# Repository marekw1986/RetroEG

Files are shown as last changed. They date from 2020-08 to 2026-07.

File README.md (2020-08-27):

# RetroEG

## Overwiev
This is repository of firmware for RetroGeiger project - a Geiger counter made of retro parts. 
It uses WDC65C02 CPU and some vintage peripherals, like R65C51 UART, M6242B RTC or MC6840 timer. 
You can find description of this project on my [Hackaday.io profile](https://hackaday.io/project/167980-retrogeiger).

This project is still in development.

## Required tools
You need [cc65](https://github.com/cc65/cc65) to build this project.

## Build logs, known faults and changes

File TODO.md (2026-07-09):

# RetroGeiger
Geiger counter build around 6502 CPU

### Tasks
- [ ] Debug write issue. For some reason writing to 8255 and EEPROM fails. Maybe /WR signal should be delayed.

### Completed Column ✓
- [x] Add modbus support

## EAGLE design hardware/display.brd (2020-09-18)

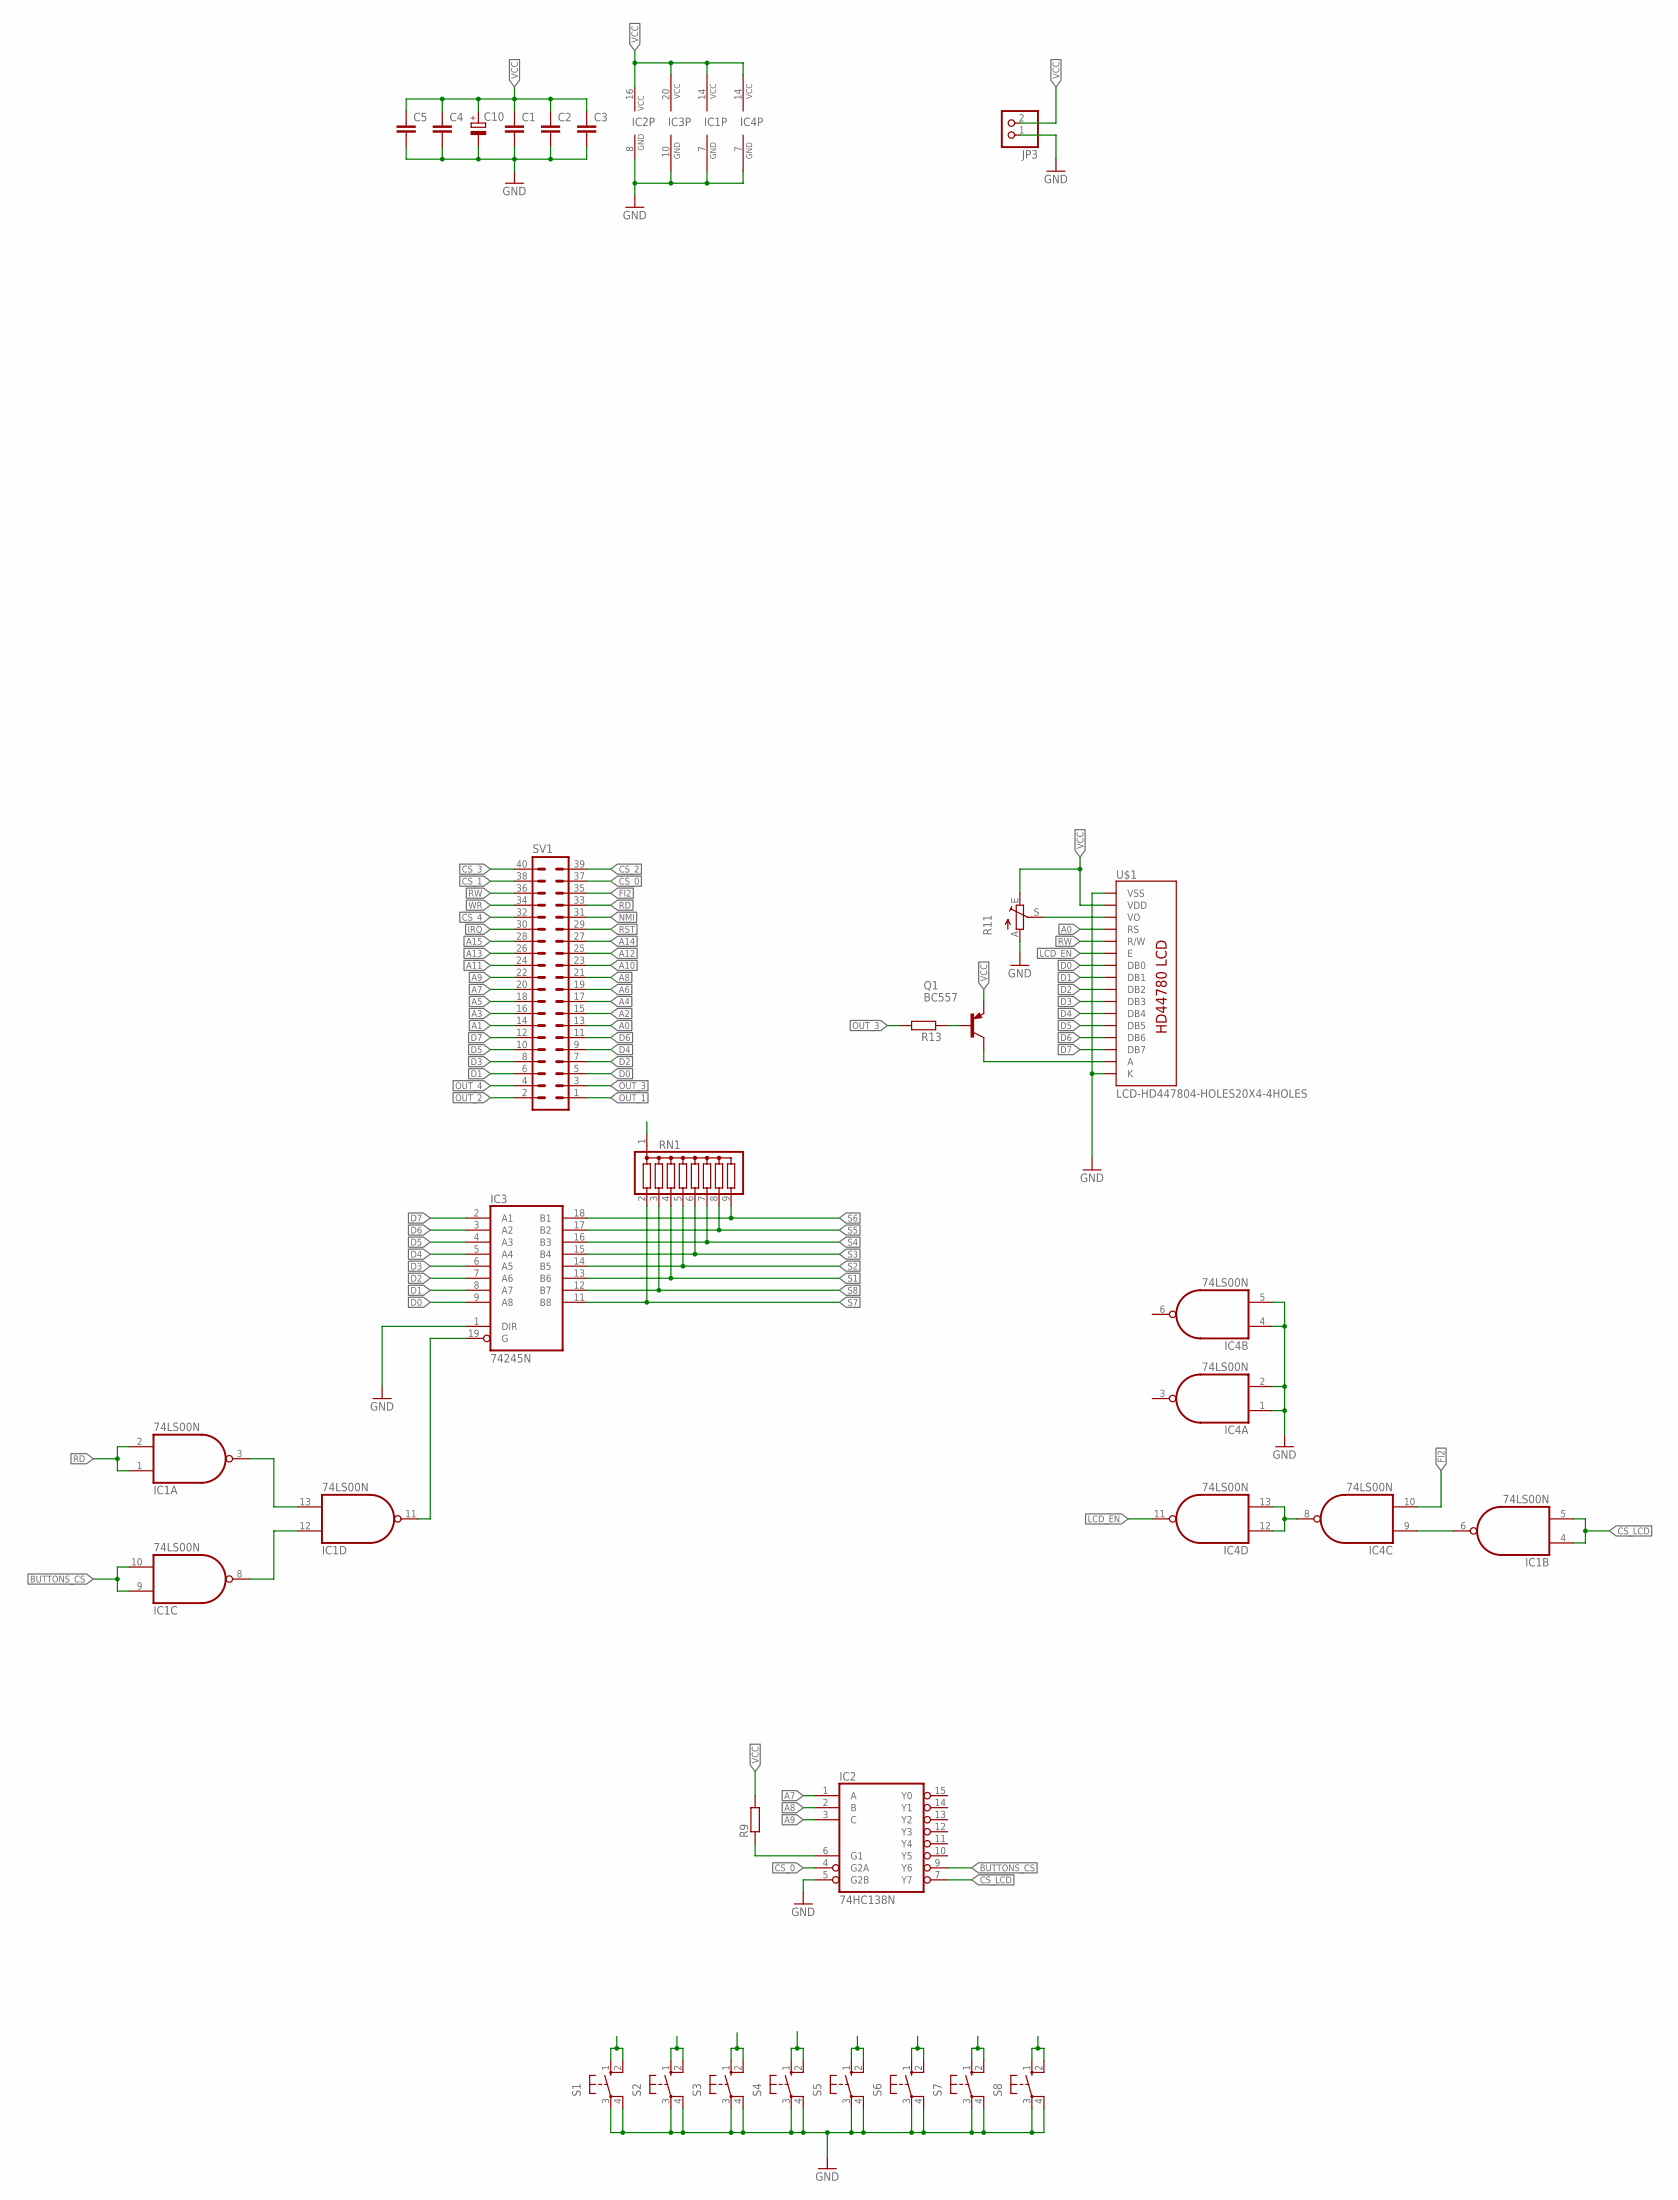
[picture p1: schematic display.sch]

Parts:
C1: C-EUC0603; C0603
C2, C3, C4, C5: C-EUC1206; C1206
C10: CPOL-EUE5-10.5; E5-10,5
IC1, IC4: 74LS00N; DIL14
IC2: 74HC138N; DIL16
IC3: 74245N; DIL20
JP3: PINHD-1X2/90; 1X02/90
Q1: BC557; TO92
R9, R13: R-EU_0204/7; 0204/7
R11: TRIM_EU-B25U; B25U
RN1: G08R; SIL9
S1, S2, S3, S4, S5, S6, S7, S8: 40-XX; B3F-40XX
SV1: ML40L
U$1: LCD-HD447804-HOLES20X4-4HOLES; LCD-20X4-4HOLES

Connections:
A0: SV1.13, U$1.P$4 (RS)
A1: SV1.14
A2: SV1.15
A3: SV1.16
A4: SV1.17
A5: SV1.18
A6: SV1.19
A7: IC2.1 (A), SV1.20
A8: IC2.2 (B), SV1.21
A9: IC2.3 (C), SV1.22
A10: SV1.23
A11: SV1.24
A12: SV1.25
A13: SV1.26
A14: SV1.27
A15: SV1.28
BUTTONS_CS: IC1.9 (I0), IC1.10 (I1), IC2.9 (Y6)
CS_0: IC2.4 (G2A), SV1.37
CS_1: SV1.38
CS_2: SV1.39
CS_3: SV1.40
CS_4: SV1.32
CS_LCD: IC1.4 (I0), IC1.5 (I1), IC2.7 (Y7)
D0: IC3.9 (A8), SV1.5, U$1.P$7 (DB0)
D1: IC3.8 (A7), SV1.6, U$1.P$8 (DB1)
D2: IC3.7 (A6), SV1.7, U$1.P$9 (DB2)
D3: IC3.6 (A5), SV1.8, U$1.P$10 (DB3)
D4: IC3.5 (A4), SV1.9, U$1.P$11 (DB4)
D5: IC3.4 (A3), SV1.10, U$1.P$12 (DB5)
D6: IC3.3 (A2), SV1.11, U$1.P$13 (DB6)
D7: IC3.2 (A1), SV1.12, U$1.P$14 (DB7)
FI2: IC4.10 (I1), SV1.35
GND: C1.2, C2.2, C3.2, C4.2, C5.2, C10.-, IC1.7 (GND), IC2.5 (G2B), IC2.8 (GND), IC3.1 (DIR), IC3.10 (GND), IC4.1 (I0), IC4.2 (I1), IC4.4 (I0), IC4.5 (I1), IC4.7 (GND), JP3.1, R11.A, S1.3, S1.4 (P1), S2.3, S2.4 (P1), S3.3, S3.4 (P1), S4.3, S4.4 (P1), S5.3, S5.4 (P1), S6.3, S6.4 (P1), S7.3, S7.4 (P1), S8.3, S8.4 (P1), U$1.P$1 (VSS), U$1.P$16 (K)
IRQ: SV1.30
LCD_EN: IC4.11 (O), U$1.P$6 (E)
unnamed: IC1.11 (O), IC3.19 (G)
unnamed: Q1.3 (C), U$1.P$15 (A)
unnamed: IC4.8 (O), IC4.12 (I0), IC4.13 (I1)
unnamed: IC1.6 (O), IC4.9 (I0)
unnamed: Q1.2 (B), R13.1
unnamed: IC1.3 (O), IC1.13 (I1)
unnamed: IC1.8 (O), IC1.12 (I0)
unnamed: IC2.6 (G1), R9.1
unnamed: R11.S, U$1.P$3 (VO)
NMI: SV1.31
OUT_1: SV1.1
OUT_2: SV1.2
OUT_3: R13.2, SV1.3
OUT_4: SV1.4
RD: IC1.1 (I0), IC1.2 (I1), SV1.33
RST: SV1.29
RW: SV1.36, U$1.P$5 (R/W)
S1: IC3.13 (B6), RN1.4, S1.1 (S), S1.2 (S1)
S2: IC3.14 (B5), RN1.5, S2.1 (S), S2.2 (S1)
S3: IC3.15 (B4), RN1.6, S3.1 (S), S3.2 (S1)
S4: IC3.16 (B3), RN1.7, S4.1 (S), S4.2 (S1)
S5: IC3.17 (B2), RN1.8, S5.1 (S), S5.2 (S1)
S6: IC3.18 (B1), RN1.9, S6.1 (S), S6.2 (S1)
S7: IC3.11 (B8), RN1.2, S7.1 (S), S7.2 (S1)
S8: IC3.12 (B7), RN1.3, S8.1 (S), S8.2 (S1)
VCC: C1.1, C2.1, C3.1, C4.1, C5.1, C10.+, IC1.14 (VCC), IC2.16 (VCC), IC3.20 (VCC), IC4.14 (VCC), JP3.2, Q1.1 (E), R9.2, R11.E, RN1.1, U$1.P$2 (VDD)
WR: SV1.34

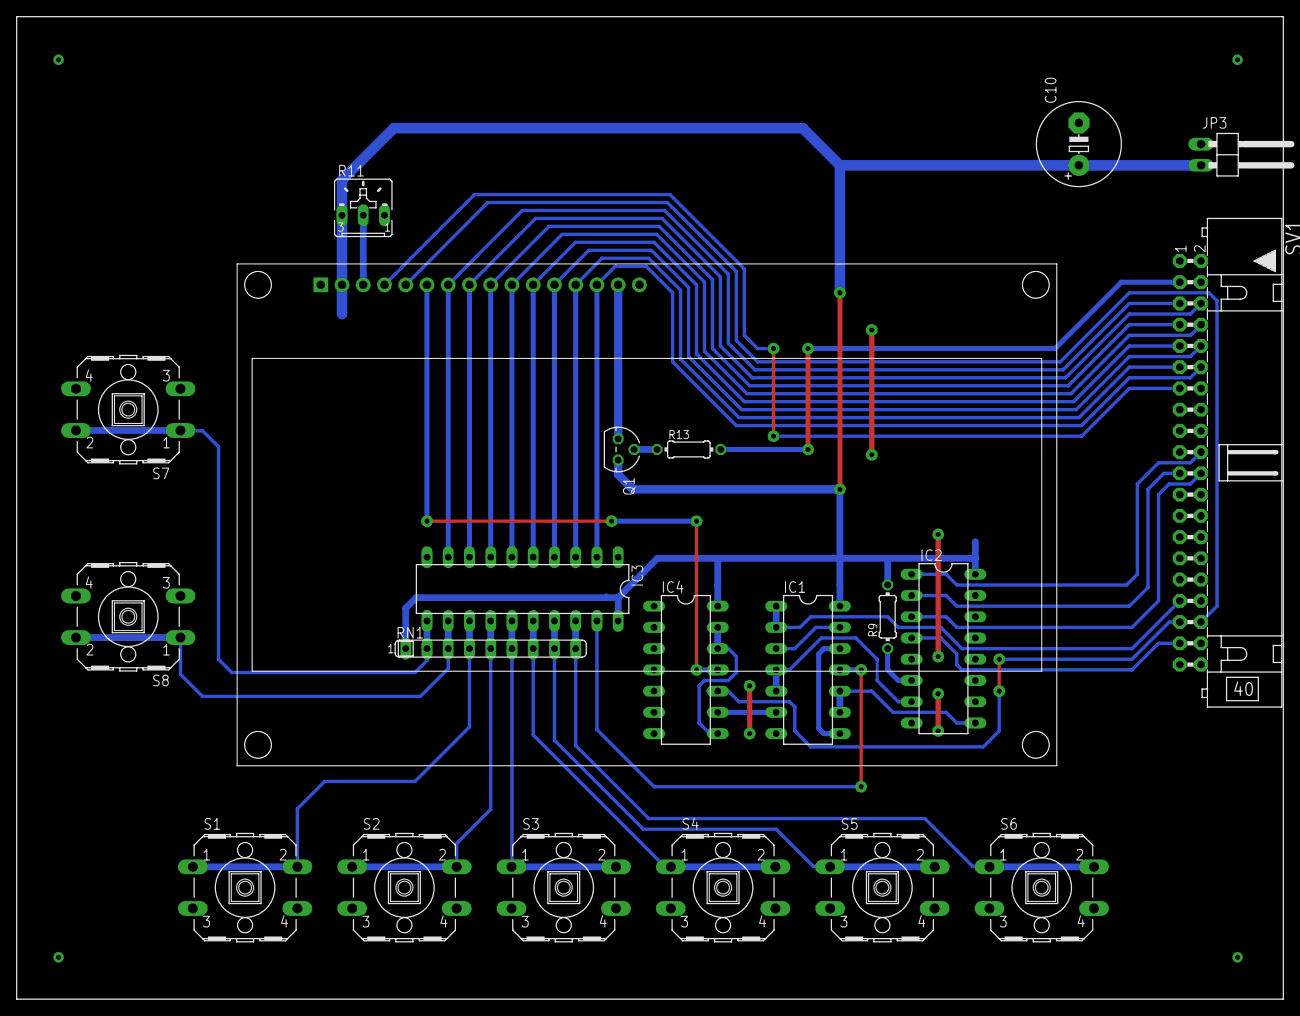
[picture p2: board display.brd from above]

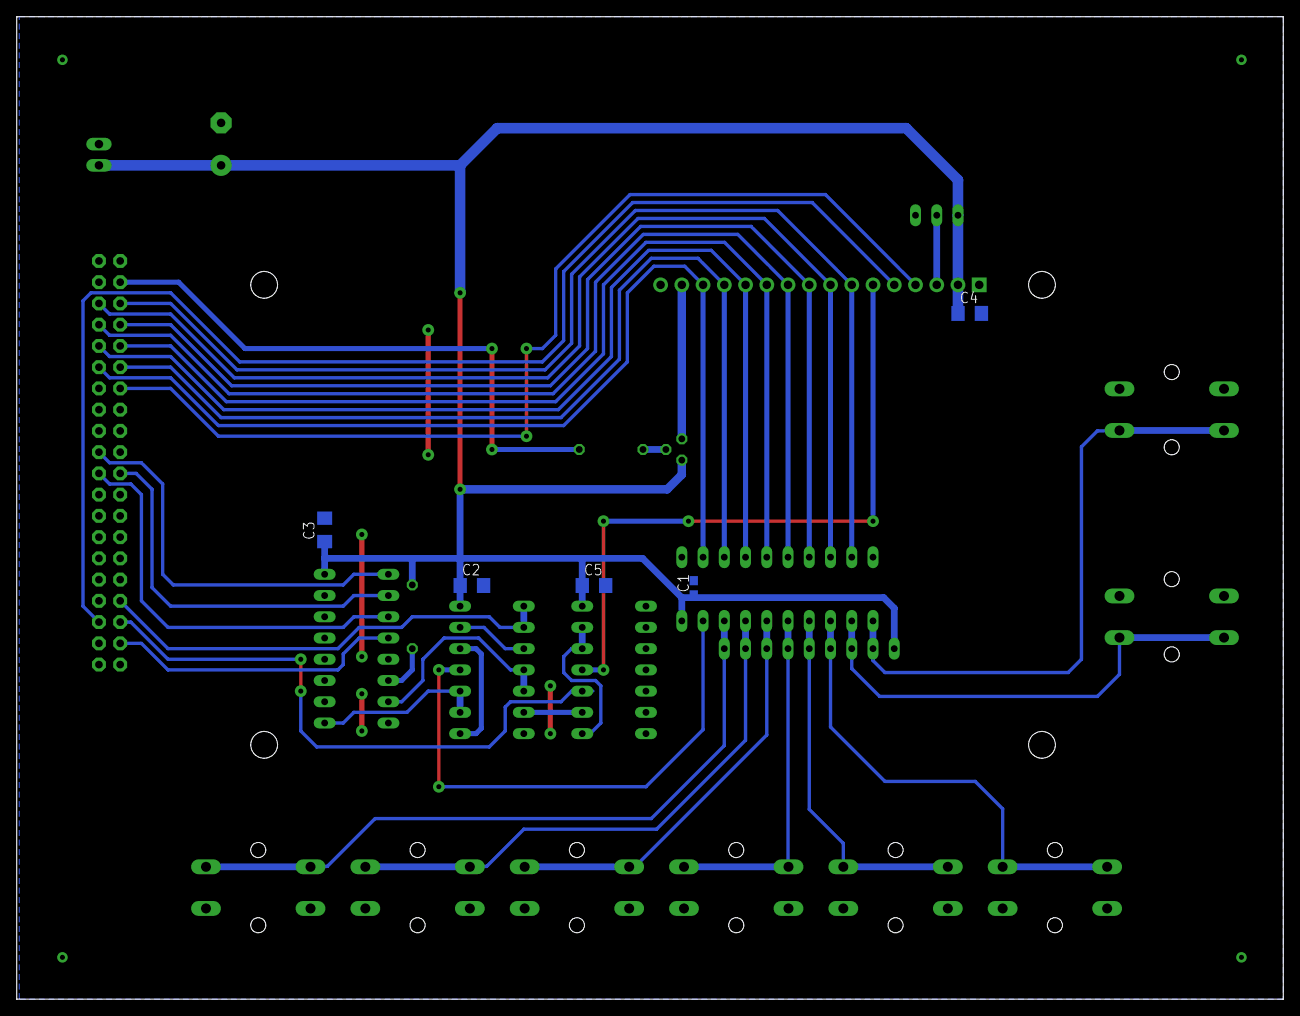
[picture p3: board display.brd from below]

Board: 2 copper layers, 151.4 x 117.5 mm, 26 parts (5 on the bottom side), 39 nets.

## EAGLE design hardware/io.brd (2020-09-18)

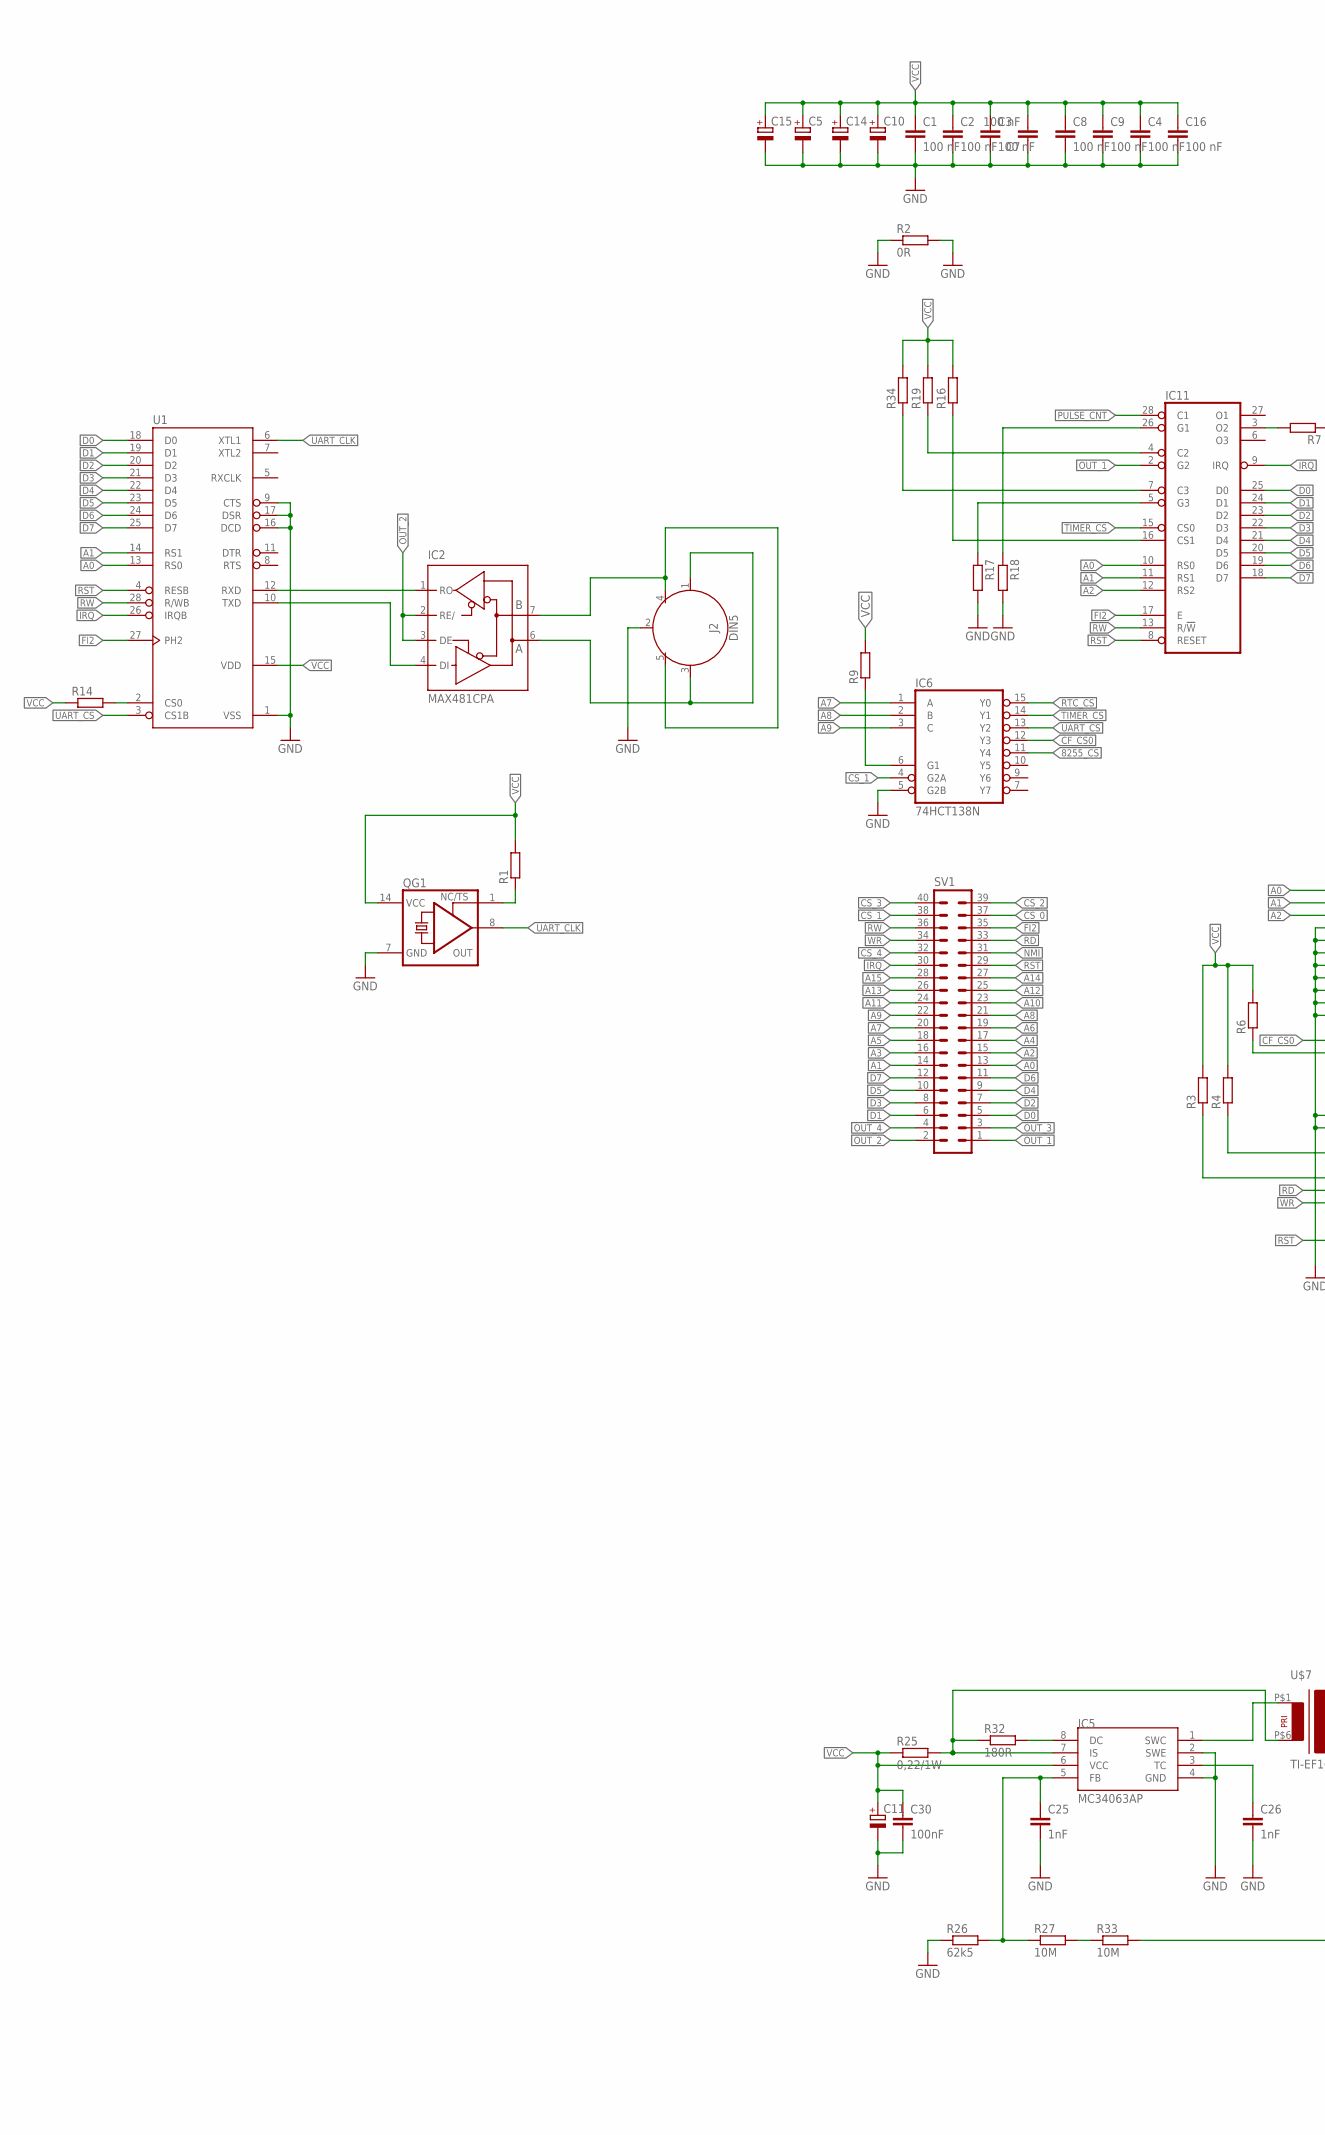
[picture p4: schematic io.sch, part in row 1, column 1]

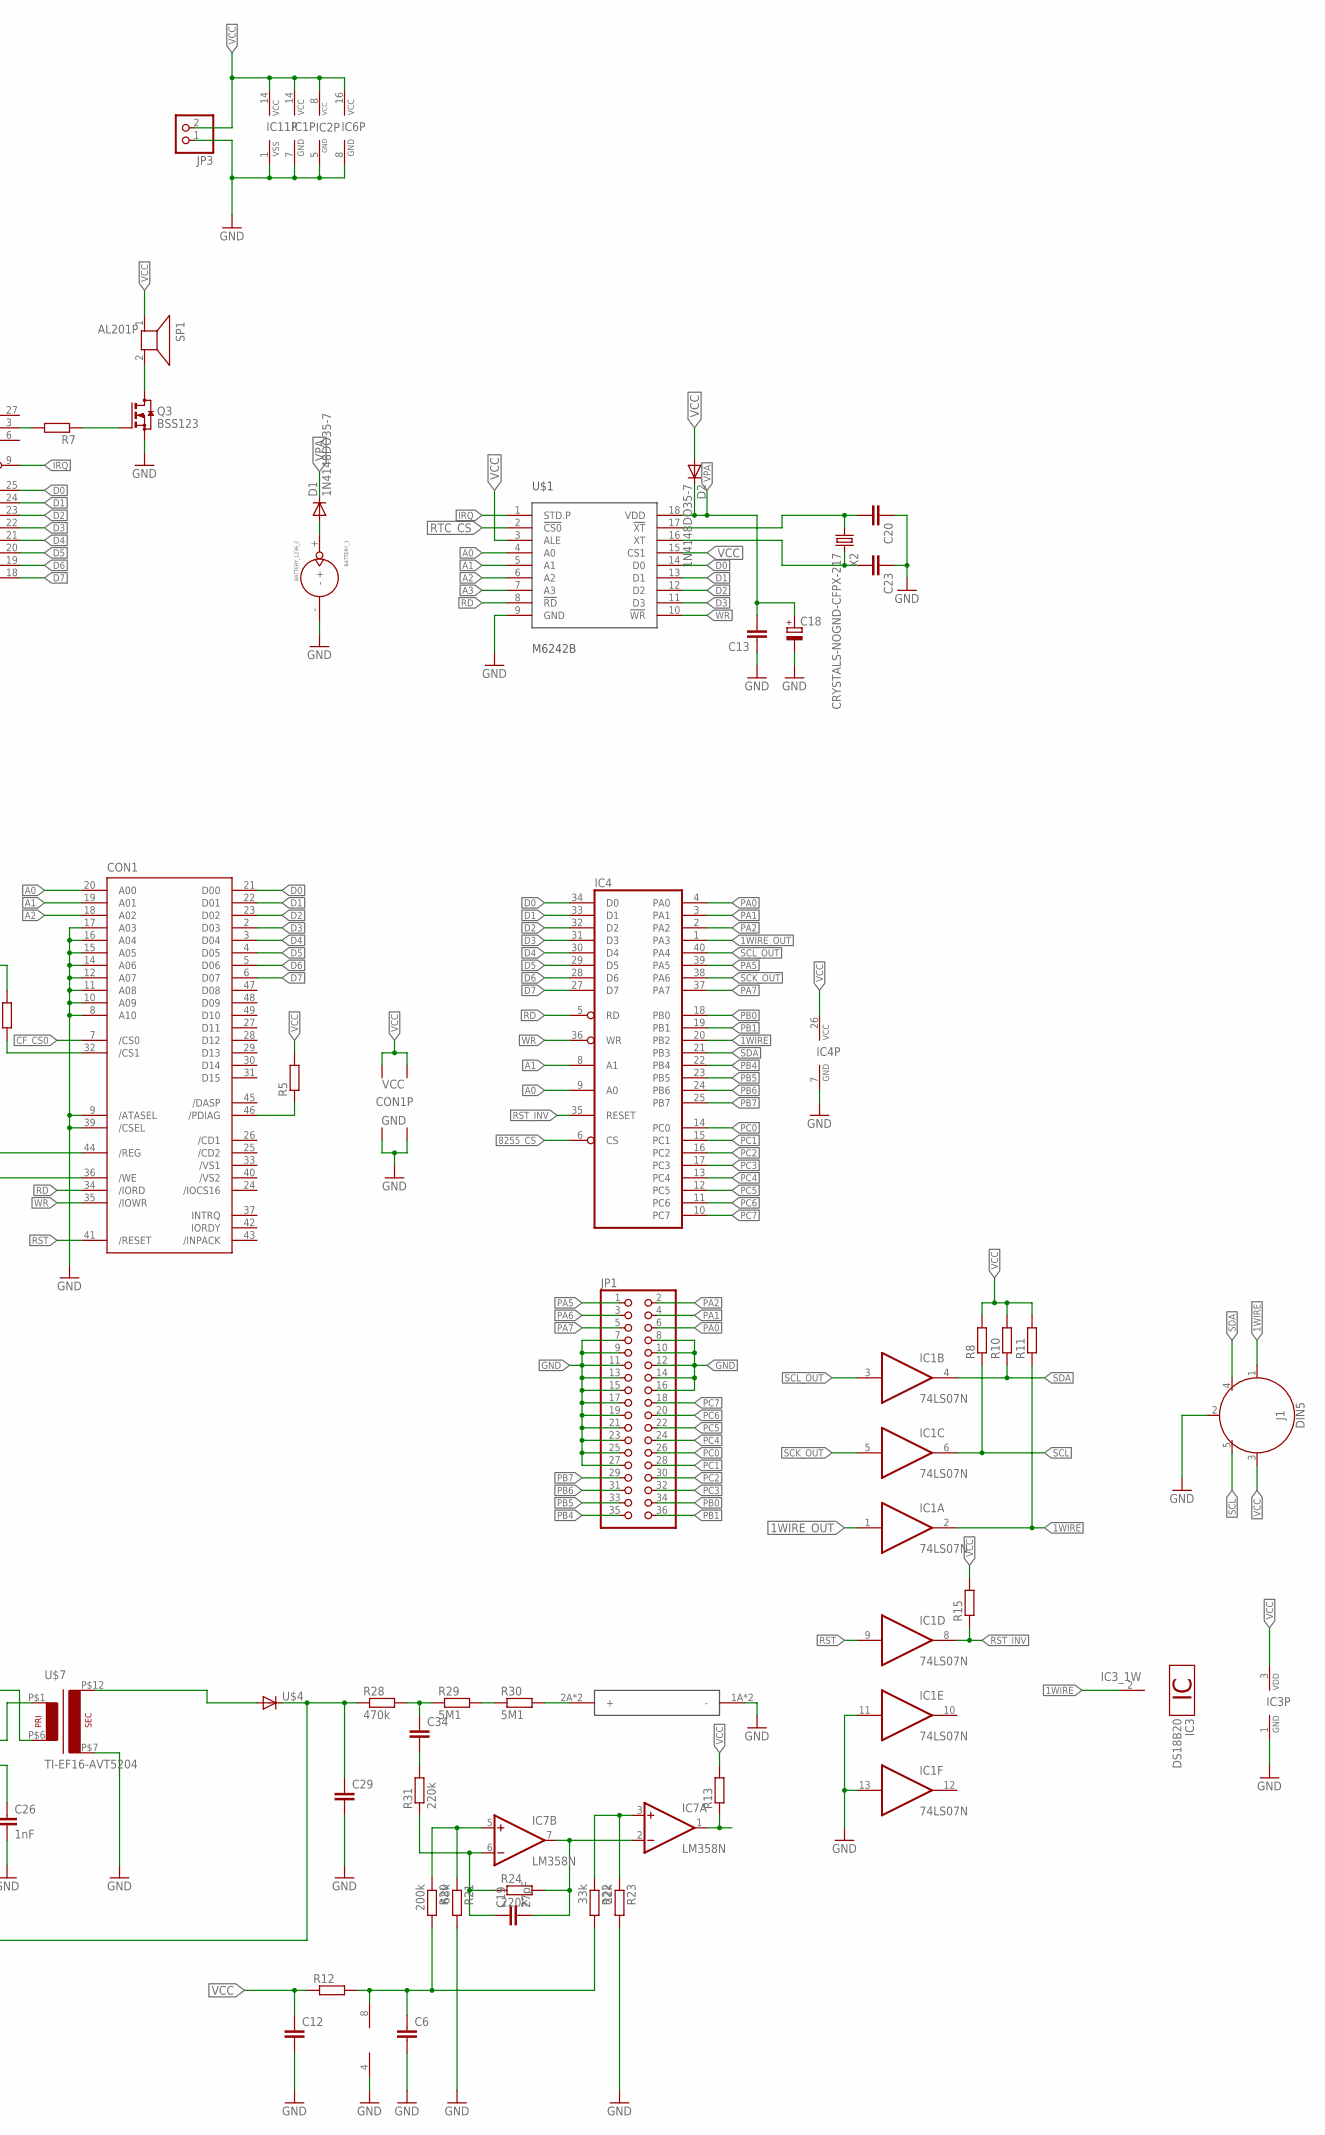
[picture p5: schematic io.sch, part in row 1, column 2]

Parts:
BATTERY_1: BATTERY_1236_C
C1, C2, C3, C8, C9: 100 nF; C1206
C4, C7, C16: 100 nF; C0603
C5: CPOL-EUSMCC; SMC_C
C6, C12, C13, C20, C23: C-EUC0603; C0603
C10, C15: CPOL-EUE5-10.5; E5-10,5
C11: CPOL-EUSMCE; SMC_E
C14: CPOL-EUE3.5-8; E3,5-8
C18: CPOL-EUSMCB; SMC_B
C19: 27pF; C0603
C25, C26: 1nF; C0603
C29: C-EU225-113X268; C225-113X268
C30: 100nF; C0603
C34: C-EU050-024X044; C050-024X044
CON1: CF-CARD-IDE_MODE; MI20-50PD-SF
D1, D2: 1N4148DO35-7; DO35-7
IC1: 74LS07N; DIL14
IC2: MAX481CPA; DIL08
IC3: DS18B20; TO92-
IC4: 8255A; DIL40
IC5: MC34063AP; DIL08
IC6: 74HCT138N; DIL16
IC7: LM358N; DIL08
IC11: 6840; DIL28
J1, J2: DIN5; DIN5-RA-PTH
JP1: PINHD-2X18; 2X18
JP3: PINHD-1X2/90; 1X02/90
Q3: BSS123; SOT23
QG1: XO-14; DIL14S
R1, R9: R-EU_R1206; R1206
R2: 0R; M1206
R3, R4, R5, R6, R13, R14, R15, R18, R34: R-EU_R0603; R0603
R7, R19: R-EU_0204/5; 0204/5
R8, R10, R11, R12, R17: R-EU_0204/7; 0204/7
R16: R-EU_R0402; R0402
R20: 200k; R0603
R21: 68k; R0603
R22: 33k; R0603
R23: 22k; R0603
R24: 220k; R0603
R25: 0,22/1W; R2010
R26: 62k5; R1206
R27, R33: 10M; 0204/7
R28: 470k; R2512
R29, R30: 5M1; R2512
R31: 220k; 0204/7
R32: 180R; R0805
SP1: AL201P
SV1: ML40L
U1: G65SC51P; DIP-28
U$1: M6242B; DIL18
U$4: DIODE-MELF-MLL41; MELF-MLL41
U$5: STS5; GEIGERTUBE
U$7: TI-EF16-AVT5204; EF16-K-H-12P-12,5
X2: CRYSTALS-NOGND-CFPX-217; 3.2X1.5-2-PAD

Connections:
1WIRE: IC1.2 (O), IC3.2 (1W), IC4.20 (PB2), J1.1, R11.1
1WIRE_OUT: IC1.1 (I), IC4.1 (PA3)
8255_CS: IC4.6 (CS), IC6.11 (Y4)
A0: CON1.20 (A00), IC4.9 (A0), IC11.10 (RS0), SV1.13, U1.13 (RS0), U$1.4 (A0)
A1: CON1.19 (A01), IC4.8 (A1), IC11.11 (RS1), SV1.14, U1.14 (RS1), U$1.5 (A1)
A2: CON1.18 (A02), IC11.12 (RS2), SV1.15, U$1.6 (A2)
A3: SV1.16, U$1.7 (A3)
A4: SV1.17
A5: SV1.18
A6: SV1.19
A7: IC6.1 (A), SV1.20
A8: IC6.2 (B), SV1.21
A9: IC6.3 (C), SV1.22
A10: SV1.23
A11: SV1.24
A12: SV1.25
A13: SV1.26
A14: SV1.27
A15: SV1.28
A_3V: C6.1, IC7.8 (V+), R12.2, R20.2, R22.2
CF_CS0: CON1.7 (/CS0), IC6.12 (Y3)
CS_0: SV1.37
CS_1: IC6.4 (G2A), SV1.38
CS_2: SV1.39
CS_3: SV1.40
CS_4: SV1.32
D0: CON1.21 (D00), IC4.34 (D0), IC11.25 (D0), SV1.5, U1.18 (D0), U$1.14 (D0)
D1: CON1.22 (D01), IC4.33 (D1), IC11.24 (D1), SV1.6, U1.19 (D1), U$1.13 (D1)
D2: CON1.23 (D02), IC4.32 (D2), IC11.23 (D2), SV1.7, U1.20 (D2), U$1.12 (D2)
D3: CON1.2 (D03), IC4.31 (D3), IC11.22 (D3), SV1.8, U1.21 (D3), U$1.11 (D3)
D4: CON1.3 (D04), IC4.30 (D4), IC11.21 (D4), SV1.9, U1.22 (D4)
D5: CON1.4 (D05), IC4.29 (D5), IC11.20 (D5), SV1.10, U1.23 (D5)
D6: CON1.5 (D06), IC4.28 (D6), IC11.19 (D6), SV1.11, U1.24 (D6)
D7: CON1.6 (D07), IC4.27 (D7), IC11.18 (D7), SV1.12, U1.25 (D7)
FI2: IC11.17 (E), SV1.35, U1.27 (PH2)
GND: BATTERY_1.-, C1.2, C2.2, C3.2, C4.2, C5.-, C6.2, C7.1, C8.2, C9.2, C10.-, C11.-, C12.2, C13.1, C14.-, C15.-, C16.2, C18.-, C20.1, C23.1, C25.2, C26.2, C29.2, C30.2, CON1.1 (GND1), CON1.8 (A10), CON1.9 (/ATASEL), CON1.10 (A09), CON1.11 (A08), CON1.12 (A07), CON1.14 (A06), CON1.15 (A05), CON1.16 (A04), CON1.17 (A03), CON1.39 (/CSEL), CON1.50 (GND2), IC1.7 (GND), IC1.11 (I), IC1.13 (I), IC2.5 (GND), IC3.1 (GND), IC4.7 (GND), IC5.2 (SWE), IC5.4 (GND), IC6.5 (G2B), IC6.8 (GND), IC7.4 (V-), IC11.1 (VSS), J1.2, J2.2, JP1.7, JP1.8, JP1.9, JP1.10, JP1.11, JP1.12, JP1.13, JP1.14, JP1.15, JP1.16, JP1.17, JP1.19, JP1.21, JP1.23, JP1.25, JP1.27, JP3.1, Q3.2 (S), QG1.7 (GND), R2.1, R2.2, R17.2, R18.2, R21.2, R23.2, R26.1, U1.1 (VSS), U1.9 (CTS), U1.16 (DCD), U1.17 (DSR), U$1.9 (GND), U$5.1A (-), U$5.1B (-), U$7.P$7 (P7)
HV: C29.1, R28.1, R33.2, U$4.C
IRQ: IC11.9 (IRQ), SV1.30, U1.26 (IRQB), U$1.1 (STD.P)
unnamed: QG1.1 (TS), R1.1
unnamed: C19.1, IC7.6 (-IN), R24.1, R31.1
unnamed: IC5.7 (IS), R25.2, R32.1, U$7.P$6 (P6)
unnamed: U$4.A, U$7.P$12 (P12)
unnamed: C26.1, IC5.3 (TC)
unnamed: C25.1, IC5.5 (FB), R26.2, R27.1
unnamed: R30.2, U$5.2A (+), U$5.2B (+)
unnamed: IC11.3 (O2), R7.2
unnamed: CON1.32 (/CS1), R6.1
unnamed: Q3.3 (D), SP1.2
unnamed: C19.2, IC7.2 (-IN), IC7.7 (OUT), R24.2
unnamed: IC6.6 (G1), R9.1
unnamed: CON1.44 (/REG), R4.1
unnamed: CON1.36 (/WE), R3.1
unnamed: CON1.46 (/PDIAG), R5.1
unnamed: BATTERY_1.+, D1.A
unnamed: R29.2, R30.1
unnamed: C34.1, R28.2, R29.1
unnamed: C34.2, R31.2
unnamed: IC7.5 (+IN), R20.1, R21.1
unnamed: IC7.3 (+IN), R22.1, R23.1
unnamed: R14.2, U1.2 (CS0)
unnamed: IC11.16 (CS1), R16.1
unnamed: IC5.1 (SWC), U$7.P$1 (P1)
unnamed: IC5.8 (DC), R32.2
unnamed: R27.2, R33.1
unnamed: IC11.5 (G3), R17.1
unnamed: IC11.26 (G1), R18.1
unnamed: IC11.4 (C2), R19.1
unnamed: IC11.7 (C3), R34.1
NMI: SV1.31
OUT_1: IC11.2 (G2), SV1.1
OUT_2: IC2.2 (RE/), IC2.3 (DE), SV1.2
OUT_3: SV1.3
OUT_4: SV1.4
PA0: IC4.4 (PA0), JP1.6
PA1: IC4.3 (PA1), JP1.4
PA2: IC4.2 (PA2), JP1.2
PA5: IC4.39 (PA5), JP1.1
PA6: JP1.3
PA7: IC4.37 (PA7), JP1.5
PB0: IC4.18 (PB0), JP1.34
PB1: IC4.19 (PB1), JP1.36
PB4: IC4.22 (PB4), JP1.35
PB5: IC4.23 (PB5), JP1.33
PB6: IC4.24 (PB6), JP1.31
PB7: IC4.25 (PB7), JP1.29
PC0: IC4.14 (PC0), JP1.26
PC1: IC4.15 (PC1), JP1.28
PC2: IC4.16 (PC2), JP1.30
PC3: IC4.17 (PC3), JP1.32
PC4: IC4.13 (PC4), JP1.24
PC5: IC4.12 (PC5), JP1.22
PC6: IC4.11 (PC6), JP1.20
PC7: IC4.10 (PC7), JP1.18
PULSE_CNT: IC7.1 (OUT), IC11.28 (C1), R13.1
RD: CON1.34 (/IORD), IC4.5 (RD), SV1.33, U$1.8 (!RD)
RST: CON1.41 (/RESET), IC1.9 (I), IC11.8 (RESET), SV1.29, U1.4 (RESB)
RST_INV: IC1.8 (O), IC4.35 (RESET), R15.1
RTC_CS: IC6.15 (Y0), U$1.2 (!CS0)
RW: IC11.13 (R/!W), SV1.36, U1.28 (R/WB)
RXD: IC2.1 (RO), U1.12 (RXD)
RX_A: IC2.6 (A), J2.1, J2.3
RX_B: IC2.7 (B), J2.4, J2.5
SCK_OUT: IC1.5 (I), IC4.38 (PA6)
SCL: IC1.6 (O), J1.5, R8.1
SCL_OUT: IC1.3 (I), IC4.40 (PA4)
SDA: IC1.4 (O), IC4.21 (PB3), J1.4, R10.1
SOSCI: C20.2, U$1.17 (!XT), X2.1
SOSCO: C23.2, U$1.16 (XT), X2.2
TICK: Q3.1 (G), R7.1
TIMER_CS: IC6.14 (Y1), IC11.15 (CS0)
TXD: IC2.4 (DI), U1.10 (TXD)
UART_CLK: QG1.8 (OUT), U1.6 (XTL1)
UART_CS: IC6.13 (Y2), U1.3 (CS1B)
VCC: C1.1, C2.1, C3.1, C4.1, C5.+, C7.2, C8.1, C9.1, C10.+, C11.+, C12.1, C14.+, C15.+, C16.1, C30.1, CON1.13 (VCC2), CON1.38 (VCC1), D2.A, IC1.14 (VCC), IC2.8 (VCC), IC3.3 (VDD), IC4.26 (VCC), IC5.6 (VCC), IC6.16 (VCC), IC11.14 (VCC), J1.3, JP3.2, QG1.14 (VCC), R1.2, R3.2, R4.2, R5.2, R6.2, R8.2, R9.2, R10.2, R11.2, R12.1, R13.2, R14.1, R15.2, R16.2, R19.2, R25.1, R34.2, SP1.1, U1.15 (VDD), U$1.3 (ALE), U$1.15 (CS1)
VPA: C13.2, C18.+, D1.C, D2.C, U$1.18 (VDD)
WR: CON1.35 (/IOWR), IC4.36 (WR), SV1.34, U$1.10 (!WR)

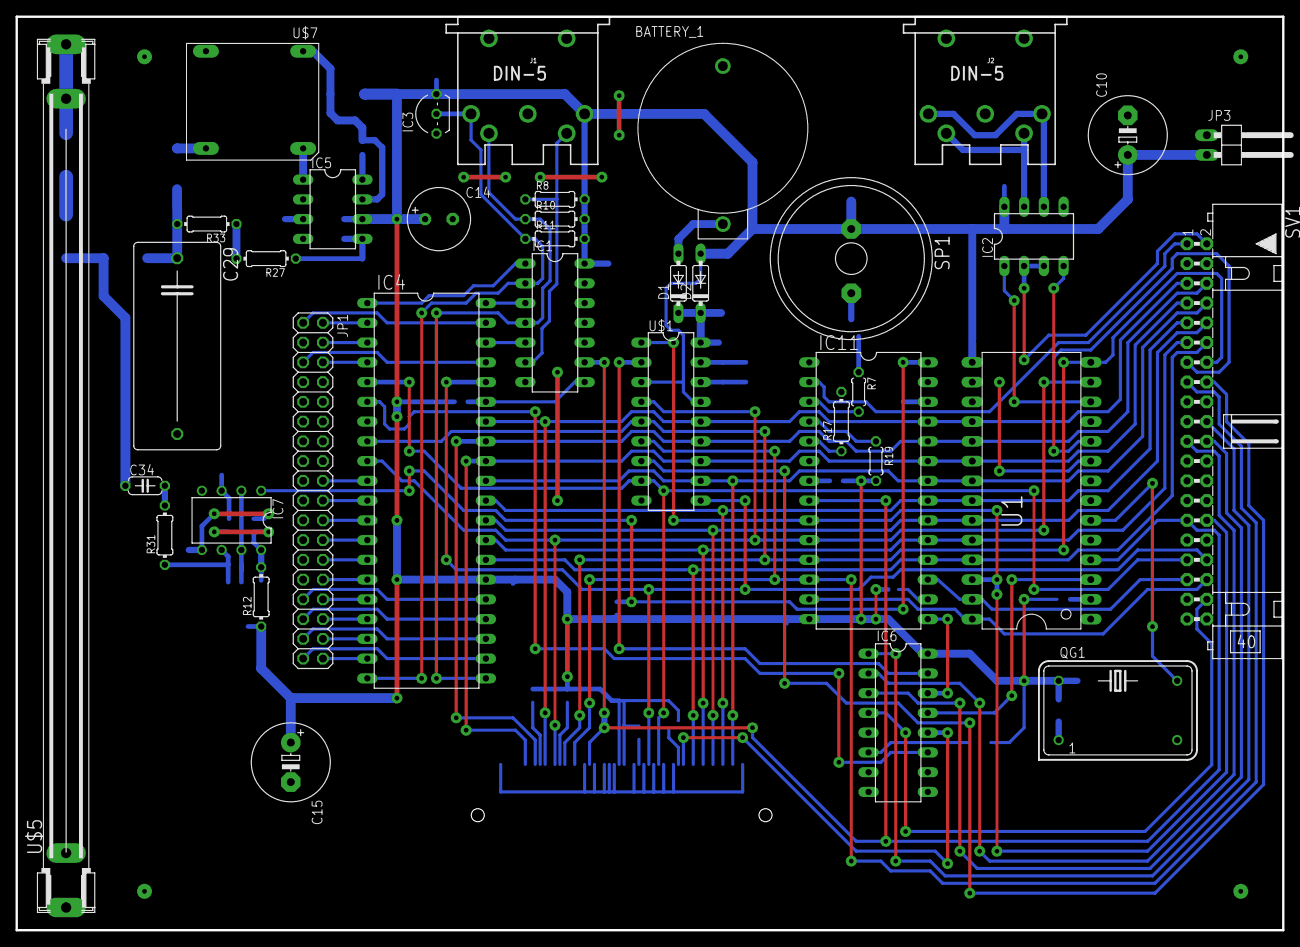
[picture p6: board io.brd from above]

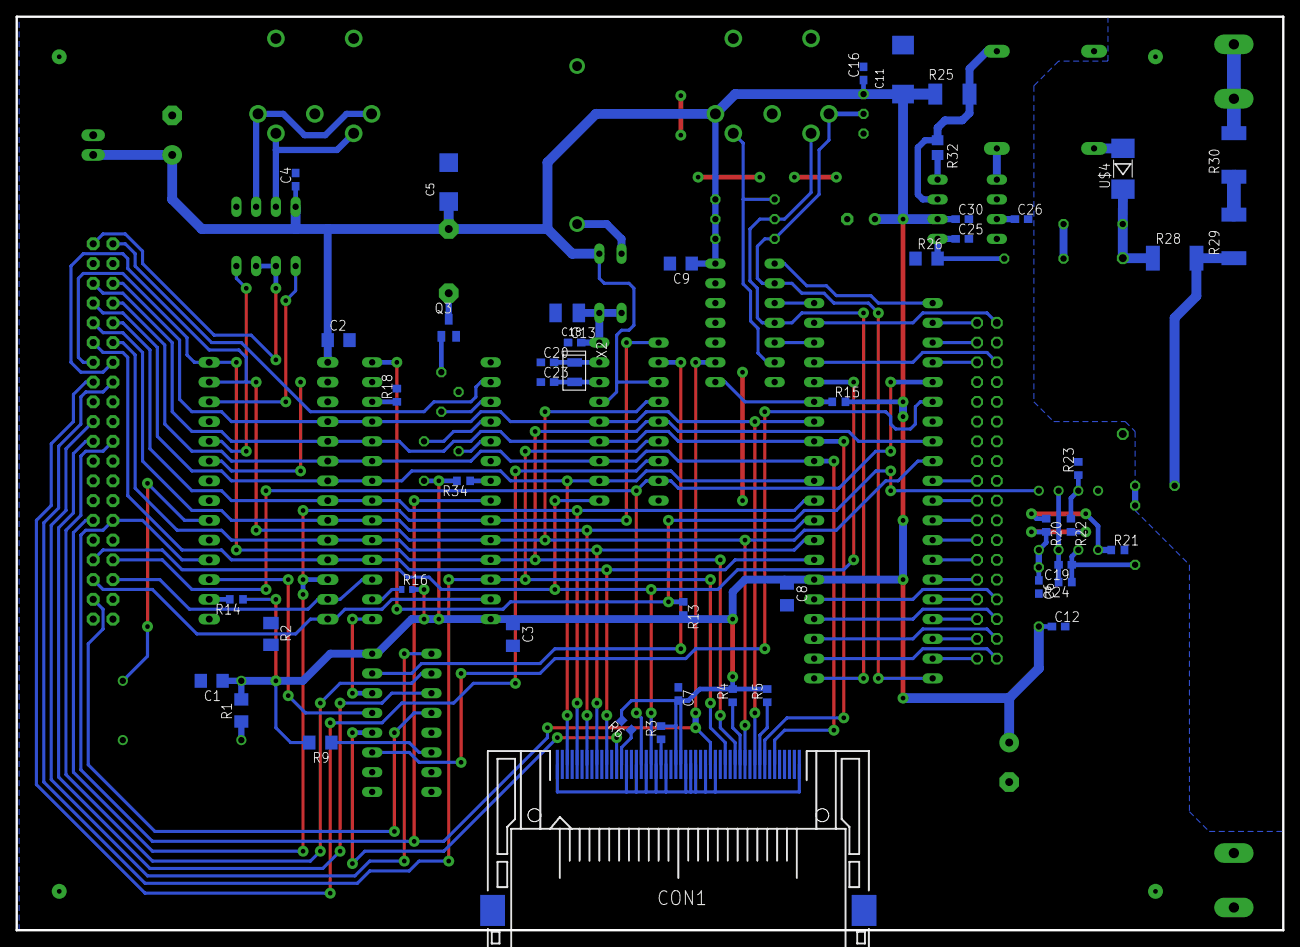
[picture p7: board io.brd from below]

Board: 2 copper layers, 162.9 x 117.5 mm, 85 parts (48 on the bottom side), 99 nets.

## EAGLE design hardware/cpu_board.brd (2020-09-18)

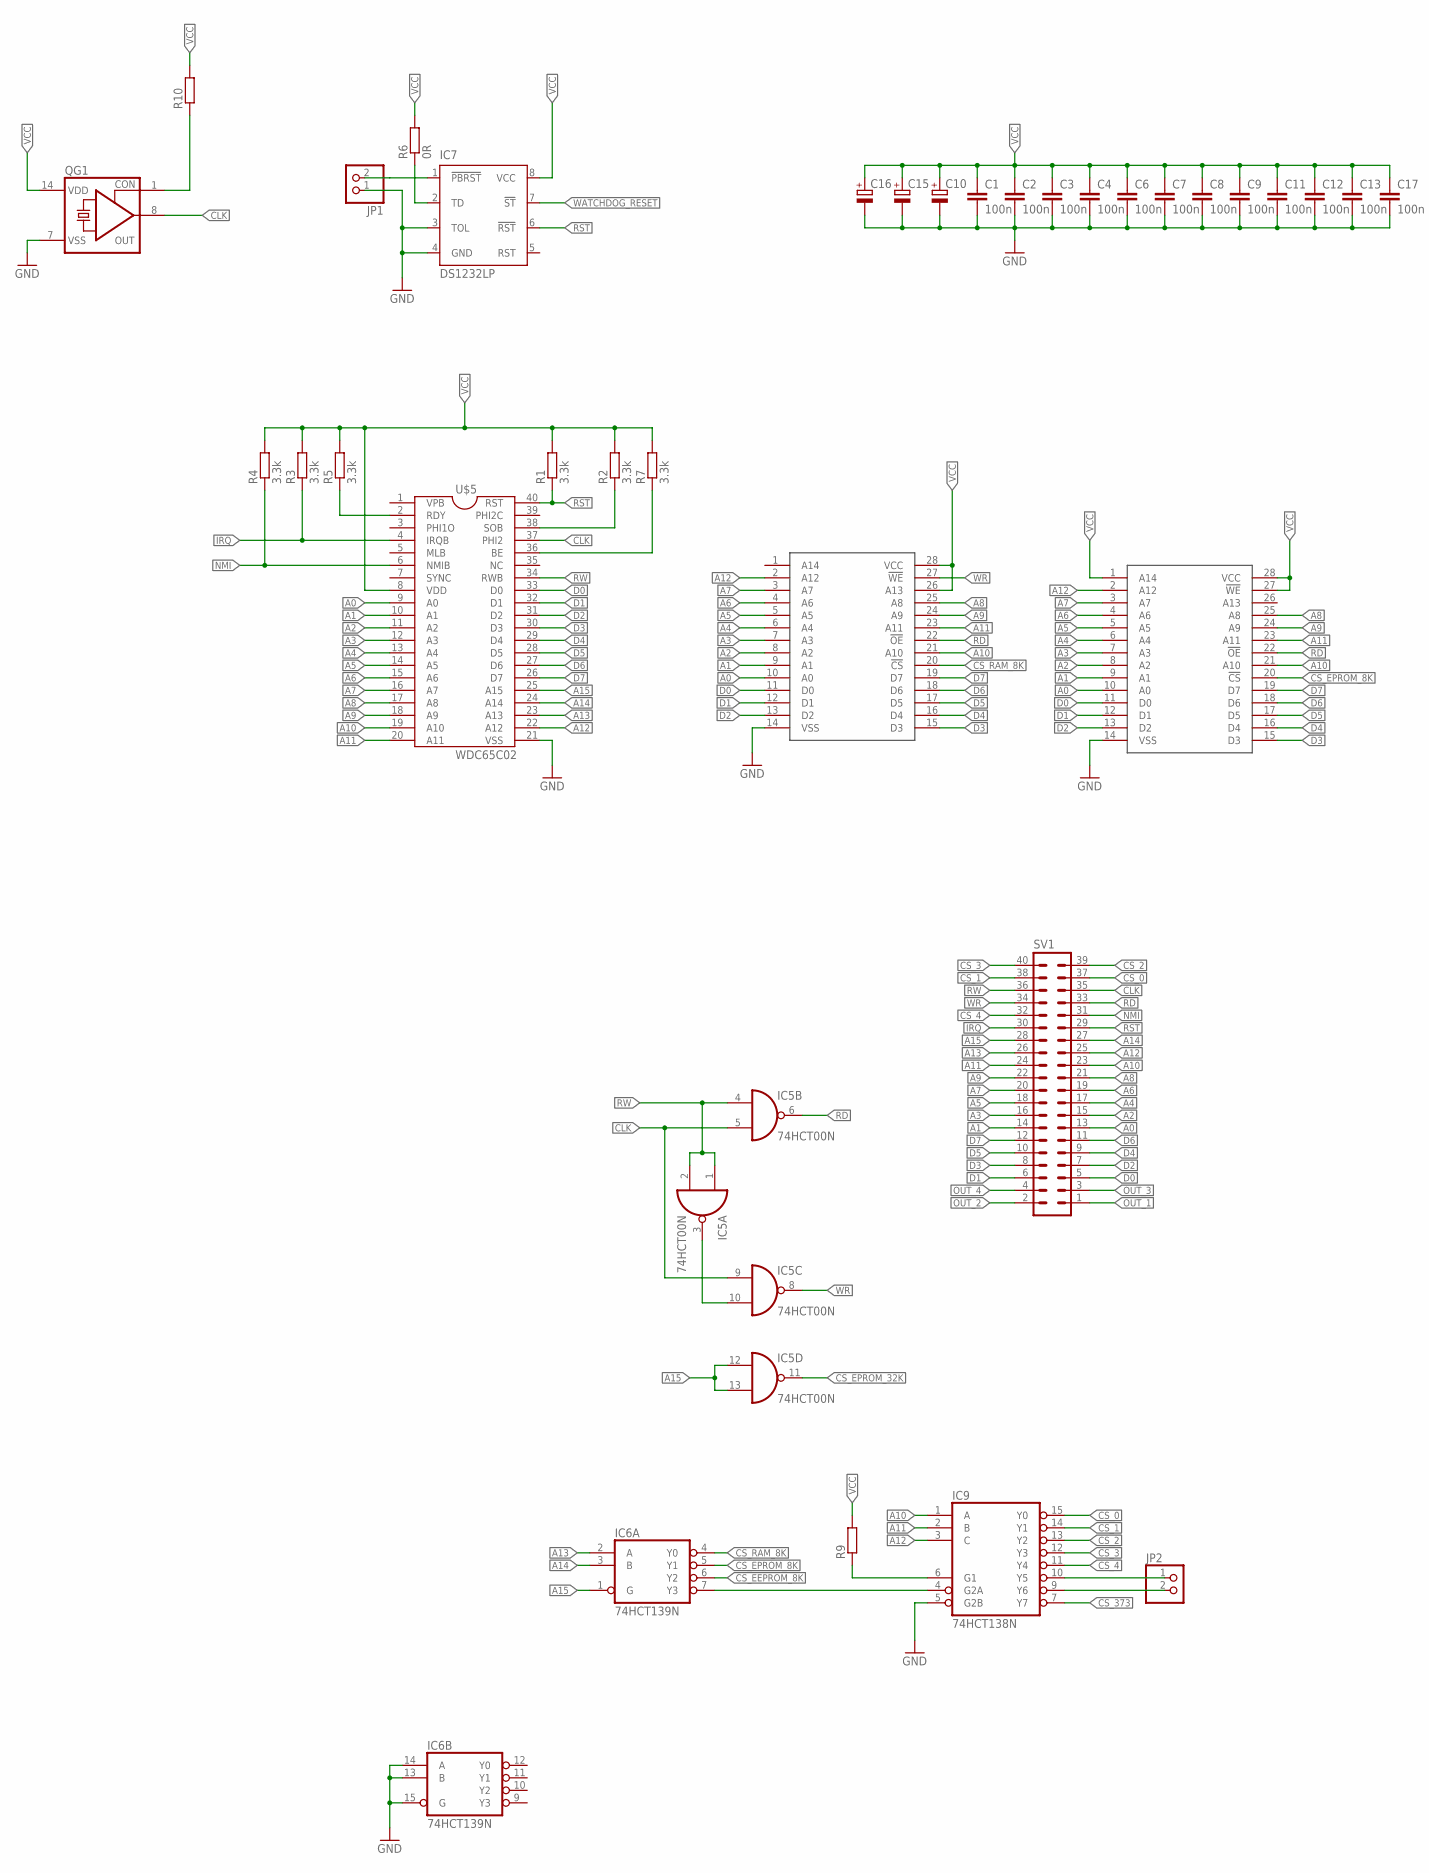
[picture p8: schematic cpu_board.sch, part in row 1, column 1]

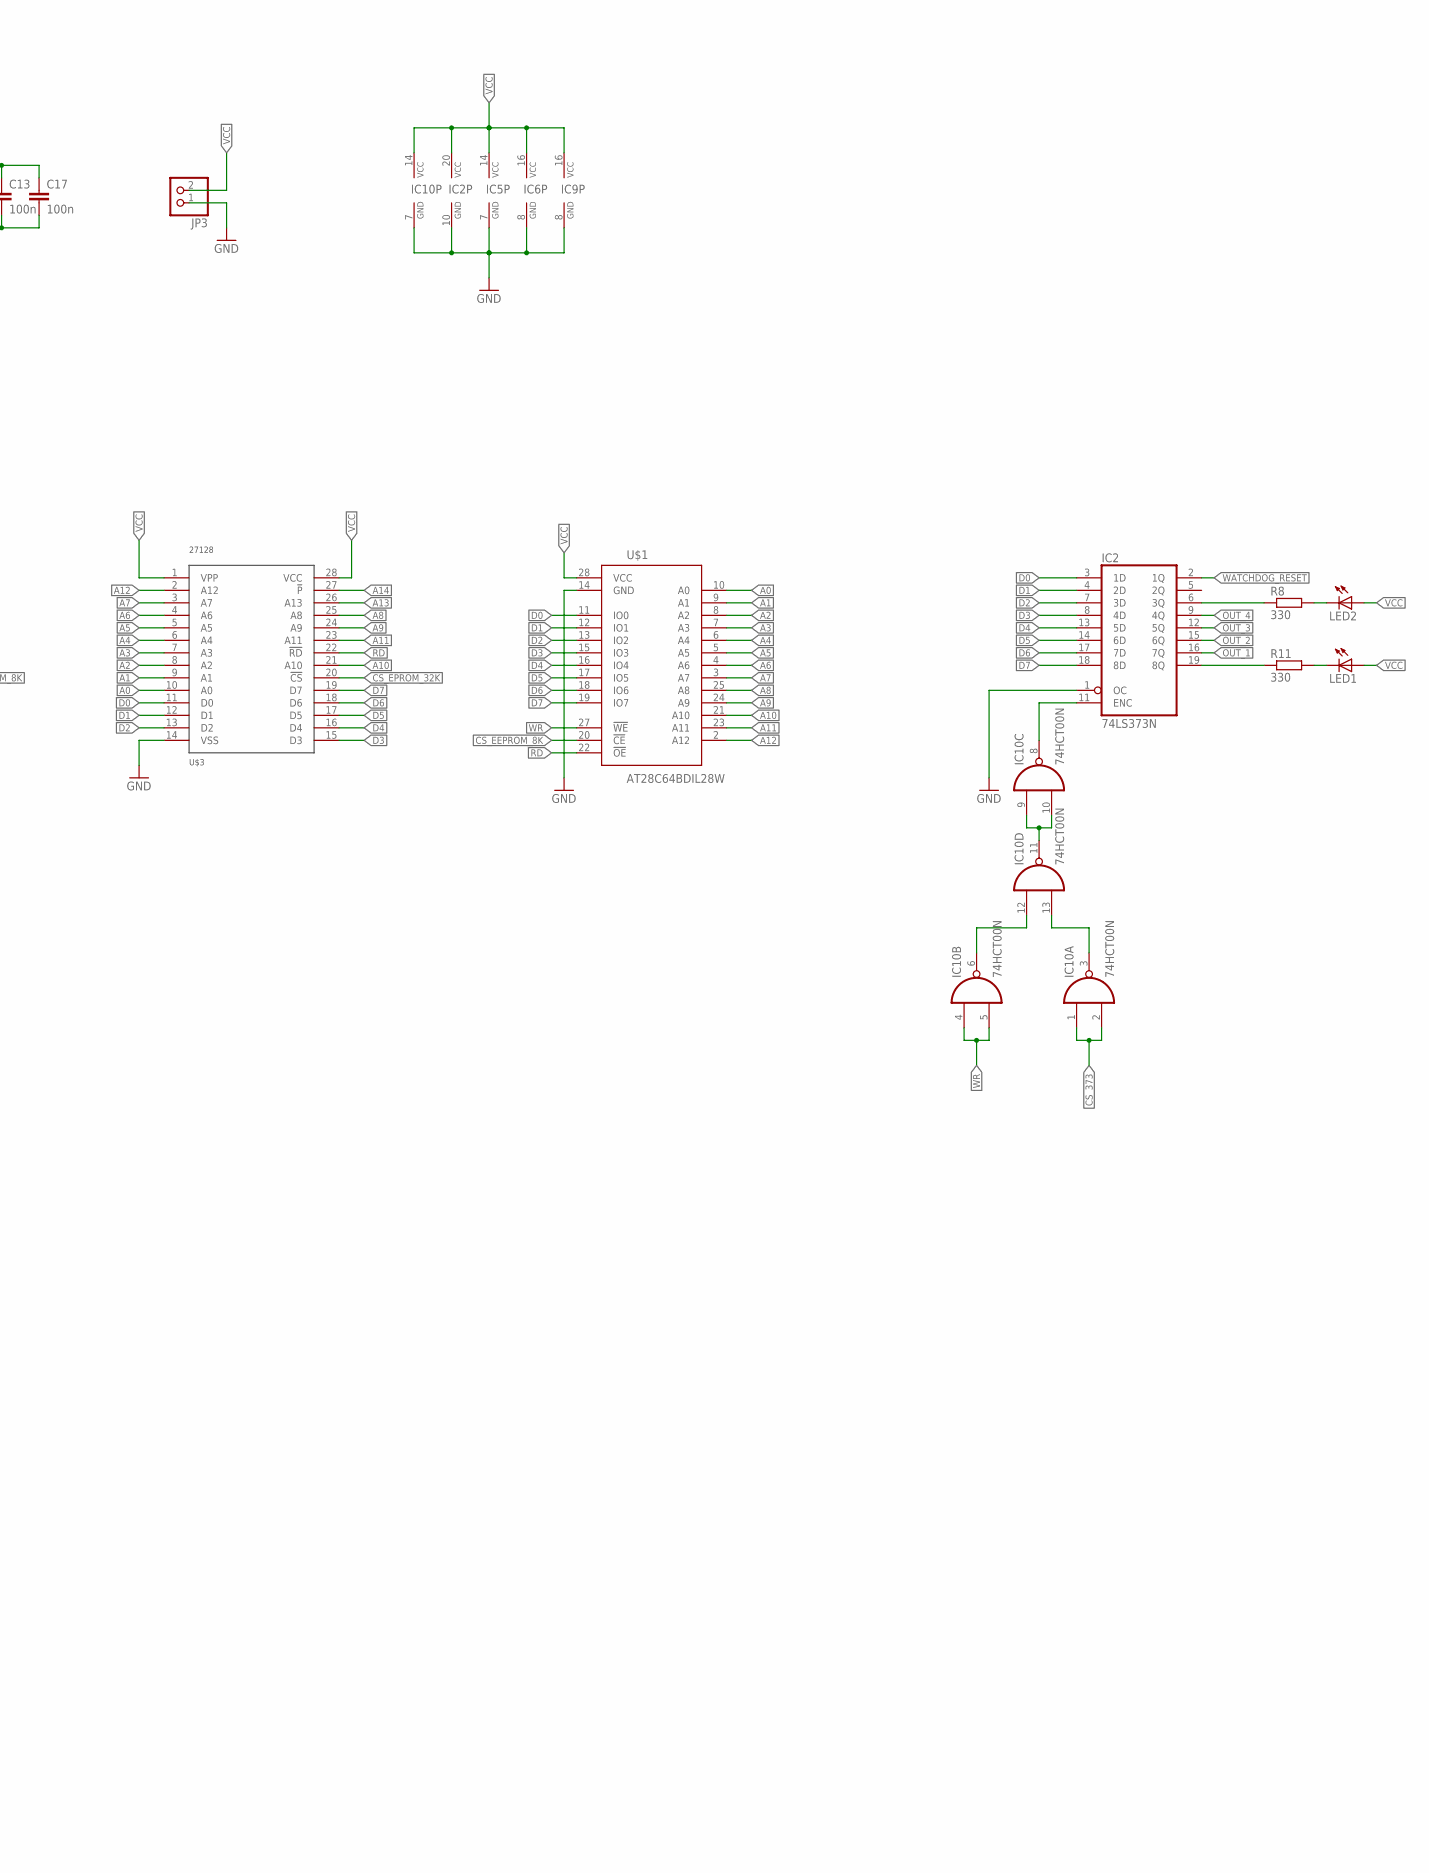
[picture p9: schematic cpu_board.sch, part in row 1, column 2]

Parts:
C1, C2, C3, C4, C6, C7, C8, C9, C17: 100n; C1206
C10: CPOL-EUE5-10.5; E5-10,5
C11, C12, C13: 100n; C0805
C15, C16: CPOL-EUSMCB; SMC_B
IC2: 74LS373N; DIL20
IC5, IC10: 74HCT00N; DIL14
IC6: 74HCT139N; DIL16
IC7: DS1232LP; DIL08
IC9: 74HCT138N; DIL16
JP1, JP2: PINHD-1X2; 1X02
JP3: PINHD-1X2/90; 1X02/90
LED1, LED2: LED5MM
QG1: CRYSTAL_RES-SG51; SG51
R1, R2, R3, R4, R5, R7: 3.3k; R1206
R6: 0R; R1206
R8, R11: 330; R1206
R9: R-EU_0204/7; 0204/7
R10: R-EU_R1206; R1206
SV1: ML40L
U$1: AT28C64BDIL28W; DIL28-6
U$2, U$4: 62256; DIL28-6
U$3: 27128; DIL28
U$5: WDC65C02; DIL40

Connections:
A0: SV1.13, U$1.10 (A0), U$2.10 (A0), U$3.10 (A0), U$4.10 (A0), U$5.9 (A0)
A1: SV1.14, U$1.9 (A1), U$2.9 (A1), U$3.9 (A1), U$4.9 (A1), U$5.10 (A1)
A2: SV1.15, U$1.8 (A2), U$2.8 (A2), U$3.8 (A2), U$4.8 (A2), U$5.11 (A2)
A3: SV1.16, U$1.7 (A3), U$2.7 (A3), U$3.7 (A3), U$4.7 (A3), U$5.12 (A3)
A4: SV1.17, U$1.6 (A4), U$2.6 (A4), U$3.6 (A4), U$4.6 (A4), U$5.13 (A4)
A5: SV1.18, U$1.5 (A5), U$2.5 (A5), U$3.5 (A5), U$4.5 (A5), U$5.14 (A5)
A6: SV1.19, U$1.4 (A6), U$2.4 (A6), U$3.4 (A6), U$4.4 (A6), U$5.15 (A6)
A7: SV1.20, U$1.3 (A7), U$2.3 (A7), U$3.3 (A7), U$4.3 (A7), U$5.16 (A7)
A8: SV1.21, U$1.25 (A8), U$2.25 (A8), U$3.25 (A8), U$4.25 (A8), U$5.17 (A8)
A9: SV1.22, U$1.24 (A9), U$2.24 (A9), U$3.24 (A9), U$4.24 (A9), U$5.18 (A9)
A10: IC9.1 (A), SV1.23, U$1.21 (A10), U$2.21 (A10), U$3.21 (A10), U$4.21 (A10), U$5.19 (A10)
A11: IC9.2 (B), SV1.24, U$1.23 (A11), U$2.23 (A11), U$3.23 (A11), U$4.23 (A11), U$5.20 (A11)
A12: IC9.3 (C), SV1.25, U$1.2 (A12), U$2.2 (A12), U$3.2 (A12), U$4.2 (A12), U$5.22 (A12)
A13: IC6.2 (A), SV1.26, U$3.26 (A13), U$5.23 (A13)
A14: IC6.3 (B), SV1.27, U$3.27 (!P), U$5.24 (A14)
A15: IC5.12 (I0), IC5.13 (I1), IC6.1 (G), SV1.28, U$5.25 (A15)
CLK: IC5.5 (I1), IC5.9 (I0), QG1.8 (OUT), SV1.35, U$5.37 (PHI2)
CS_0: IC9.15 (Y0), SV1.37
CS_1: IC9.14 (Y1), SV1.38
CS_2: IC9.13 (Y2), SV1.39
CS_3: IC9.12 (Y3), SV1.40
CS_4: IC9.11 (Y4), SV1.32
CS_373: IC9.7 (Y7), IC10.1 (I0), IC10.2 (I1)
CS_EEPROM_8K: IC6.6 (Y2), U$1.20 (!CE)
CS_EPROM_8K: IC6.5 (Y1), U$2.20 (!CS)
CS_EPROM_32K: IC5.11 (O), U$3.20 (!CS)
CS_RAM_8K: IC6.4 (Y0), U$4.20 (!CS)
D0: IC2.3 (1D), SV1.5, U$1.11 (IO0), U$2.11 (D0), U$3.11 (D0), U$4.11 (D0), U$5.33 (D0)
D1: IC2.4 (2D), SV1.6, U$1.12 (IO1), U$2.12 (D1), U$3.12 (D1), U$4.12 (D1), U$5.32 (D1)
D2: IC2.7 (3D), SV1.7, U$1.13 (IO2), U$2.13 (D2), U$3.13 (D2), U$4.13 (D2), U$5.31 (D2)
D3: IC2.8 (4D), SV1.8, U$1.15 (IO3), U$2.15 (D3), U$3.15 (D3), U$4.15 (D3), U$5.30 (D3)
D4: IC2.13 (5D), SV1.9, U$1.16 (IO4), U$2.16 (D4), U$3.16 (D4), U$4.16 (D4), U$5.29 (D4)
D5: IC2.14 (6D), SV1.10, U$1.17 (IO5), U$2.17 (D5), U$3.17 (D5), U$4.17 (D5), U$5.28 (D5)
D6: IC2.17 (7D), SV1.11, U$1.18 (IO6), U$2.18 (D6), U$3.18 (D6), U$4.18 (D6), U$5.27 (D6)
D7: IC2.18 (8D), SV1.12, U$1.19 (IO7), U$2.19 (D7), U$3.19 (D7), U$4.19 (D7), U$5.26 (D7)
GND: C1.2, C2.2, C3.2, C4.2, C6.2, C7.2, C8.2, C9.2, C10.-, C11.2, C12.2, C13.2, C15.-, C16.-, C17.2, IC2.1 (OC), IC2.10 (GND), IC5.7 (GND), IC6.8 (GND), IC6.13 (B), IC6.14 (A), IC6.15 (G), IC7.3 (TOL), IC7.4 (GND), IC9.5 (G2B), IC9.8 (GND), IC10.7 (GND), JP1.1, JP3.1, QG1.7 (VSS), U$1.14 (GND), U$2.14 (VSS), U$3.14 (VSS), U$4.14 (VSS), U$5.21 (VSS)
IRQ: R3.1, SV1.30, U$5.4 (IRQB)
unnamed: IC7.2 (TD), R6.1
unnamed: R2.1, U$5.38 (SOB)
unnamed: IC7.1 (!PBRST), JP1.2
unnamed: R7.1, U$5.36 (BE)
unnamed: R5.1, U$5.2 (RDY)
unnamed: IC2.19 (8Q), R11.1
unnamed: QG1.1 (CON), R10.1
unnamed: IC6.7 (Y3), IC9.4 (G2A)
unnamed: LED1.K (C), R11.2
unnamed: IC2.11 (ENC), IC10.8 (O)
unnamed: IC10.9 (I0), IC10.10 (I1), IC10.11 (O)
unnamed: IC10.3 (O), IC10.13 (I1)
unnamed: IC10.6 (O), IC10.12 (I0)
unnamed: IC2.6 (3Q), R8.1
unnamed: IC9.10 (Y5), JP2.1
unnamed: LED2.K (C), R8.2
unnamed: IC5.3 (O), IC5.10 (I1)
unnamed: IC9.6 (G1), R9.1
unnamed: IC9.9 (Y6), JP2.2
NMI: R4.1, SV1.31, U$5.6 (NMIB)
OUT_1: IC2.16 (7Q), SV1.1
OUT_2: IC2.15 (6Q), SV1.2
OUT_3: IC2.12 (5Q), SV1.3
OUT_4: IC2.9 (4Q), SV1.4
RD: IC5.6 (O), SV1.33, U$1.22 (!OE), U$2.22 (!OE), U$3.22 (!RD), U$4.22 (!OE)
RST: IC7.6 (!RST), R1.1, SV1.29, U$5.40 (RST)
RW: IC5.1 (I0), IC5.2 (I1), IC5.4 (I0), SV1.36, U$5.34 (RWB)
VCC: C1.1, C2.1, C3.1, C4.1, C6.1, C7.1, C8.1, C9.1, C10.+, C11.1, C12.1, C13.1, C15.+, C16.+, C17.1, IC2.20 (VCC), IC5.14 (VCC), IC6.16 (VCC), IC7.8 (VCC), IC9.16 (VCC), IC10.14 (VCC), JP3.2, LED1.A, LED2.A, QG1.14 (VDD), R1.2, R2.2, R3.2, R4.2, R5.2, R6.2, R7.2, R9.2, R10.2, U$1.28 (VCC), U$2.1 (A14), U$2.27 (!WE), U$2.28 (VCC), U$3.1 (VPP), U$3.28 (VCC), U$4.26 (A13), U$4.28 (VCC), U$5.8 (VDD)
WATCHDOG_RESET: IC2.2 (1Q), IC7.7 (!ST)
WR: IC5.8 (O), IC10.4 (I0), IC10.5 (I1), SV1.34, U$1.27 (!WE), U$4.27 (!WE)

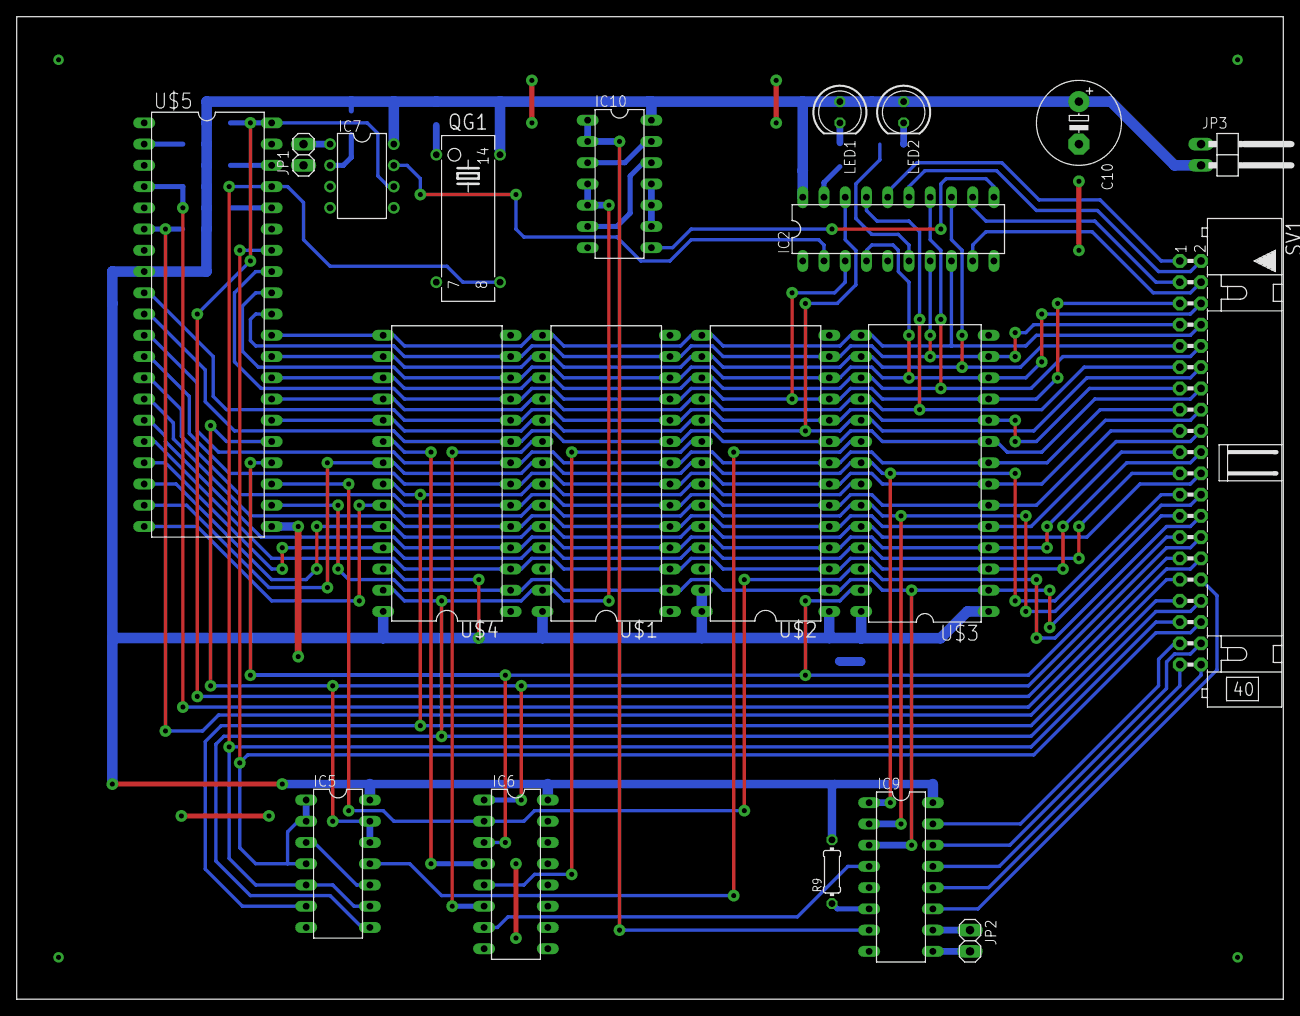
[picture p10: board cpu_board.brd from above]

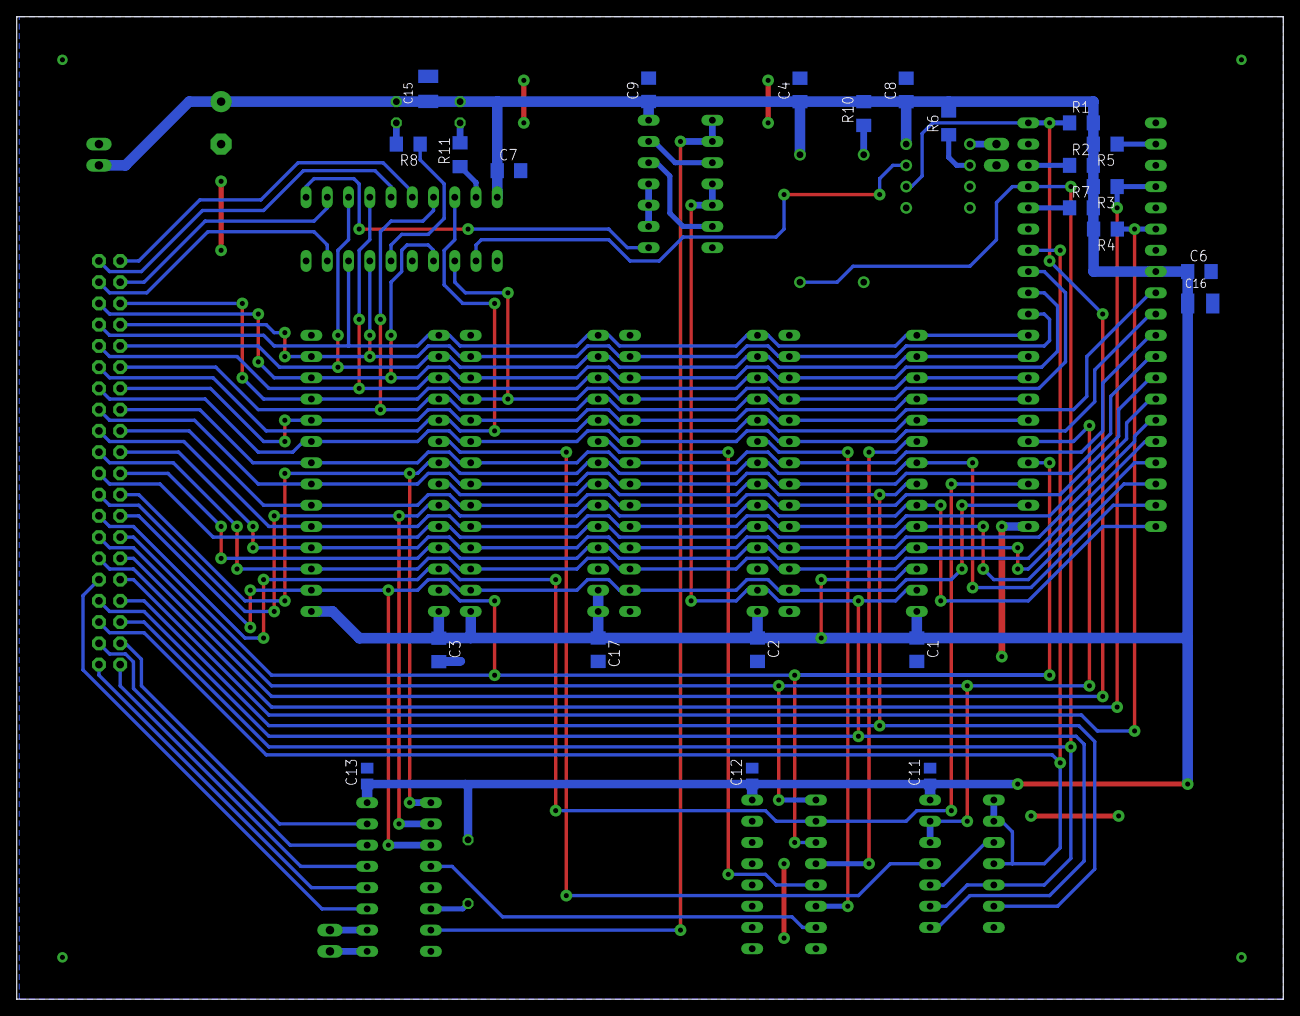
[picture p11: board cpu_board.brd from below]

Board: 2 copper layers, 151.4 x 117.5 mm, 44 parts (24 on the bottom side), 67 nets.

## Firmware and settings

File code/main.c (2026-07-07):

//0x4000 - EEPROM
//0x6000 - CS0		LCD + BUTTONS
//		0x6000 - NOT USED
//		0x6080 - NOT USED
//		0x6100 - NOT USED
//		0x6180 - NOT USED
//		0x6200 - NOT USED
//		0x6280 - NOT USED
//		0x6300 - BUTTONS
//		0x6380 - HD44780 LCD

//0x6400 - CS1
//		0x6400 - RTC
//		0x6480 - TIMER
//		0x6500 - UART
//		0x6580 - CF CARD
//		0x6600 - 8255
//		0x6680 - NOT USED
//		0x6700 - NOT USED
//		0x6780 - NOT USED

//0x6800 - CS2
//0x6C00 - CS3
//0x7000 - CS4
//0x7400 - CS5
//0x7800 - CS6
//0x7C00 - CS7

#include <stdio.h>
#include <stdint.h>
#include <stdlib.h>
#include <string.h>
#include <time.h>
#include <6502.h>
#include "config.h"
#include "hd44780.h"
#include "mos6551.h"
#include "mc6840.h"
#include "m6242.h"
#include "delay.h"
#include "modbus.h"
#include "io.h"
#include "cf.h"
#include "ff.h"
#include "bus8255.h"
#include "ds18b20.h"

FATFS cffs;
FRESULT res;
FIL file;

typedef enum {SHOW_MEAS, SHOW_TIME, SHOW_STATS} state_t;
typedef enum {MEAS_RAD=0, MEAS_TEMP, MEAS_END} meas_ind_t;

const char* titles[MEAS_END] = {"Promieniowanie", "Temperatura"};
meas_ind_t meas_ind = MEAS_RAD;

static state_t state = SHOW_MEAS;

static key_t key0, key1, key2, key3;	

static uint32_t last_uptime = 0;
static uint16_t  last_millis = 0;
static uint16_t backlight_timer = 0;
static uint8_t use_utc = 0x00;

char* __fastcall__ itoa (int val, char* buf, int radix);
char* __fastcall__ utoa (unsigned val, char* buf, int radix);
char* __fastcall__ ultoa (unsigned long val, char* buf, int radix);
char* __fastcall__ strcpy (char* s1, const char* s2);
char* __fastcall__ strcat (char* s1, const char* s2);
size_t __fastcall__ strlen (const char* s);

static void prepare_disp (void);
static void update_disp (void);
static void log_data (void);

static void key0_func (void);
static void key1_func (void);
static void key2_func (void);
static void key3_func (void);

static void update_disp_meas(void);

int main (void) {
	//char buf[32];
	
	port_write(0x91);
	
	//Initialize button structures
	key_init(&key0, BTN0, key0_func);
	key_init(&key1, BTN1, key1_func);
	key_init(&key2, BTN2, key2_func);
	key_init(&key3, BTN3, key3_func);
	
	CONF_8255 = 0x82;
	mc6840_init();
	m6242_init();
	mos6551_init();
	hd44780_init();
    modbus_init();
    bus8255_init();
	//cfInit();
	
	feed_hungry_watchdog();
	res = f_mount(&cffs, "", 1);
	modbus_set_cf_result(res);
	feed_hungry_watchdog();

	prepare_disp();
	
	CLI();
	
	while(1) {
		if (uptime() != last_uptime) {
			last_uptime = uptime();
			modbus_set_cpm();
			modbus_set_sivert();
			modbus_set_time();
			modbus_set_uptime();
			update_disp();	
		}
		
		if ( (uint16_t)(millis() - last_millis) > 240 ) {			//12x20ms
			last_millis = millis();
			port_tgl(0x84);										//Toggle both LEDs
			feed_hungry_watchdog();								// Reset watchdog
		}
        
        handle_ds18b20_poll();
		
		if (backlight_timer && ( (uint16_t)(millis()-backlight_timer) > 4000 ) ) {
			port_set(BACKLIGHT_PIN);							//Turn the backlight off
			backlight_timer = 0;
		}	

		key_update(&key0);
		key_update(&key1);
		key_update(&key2);
		key_update(&key3);
							
		mos6551_handle_rx();
		log_data();
	}
	
	return 0;
}


static void prepare_disp (void) {
	hd44780_clrscr();
	switch (state) {
		case SHOW_MEAS:
		hd44780_gotoxy(0, 0);
        hd44780_puts("                    ");
		hd44780_gotoxy(0, 0);
		hd44780_puts(titles[meas_ind]);
		break;
		
		case SHOW_TIME:
		hd44780_gotoxy(0, 0);
        hd44780_puts("                    ");
		hd44780_gotoxy(0, 0);
		hd44780_puts("Czas");
		if (use_utc) { hd44780_puts(" (UTC)"); }
		break;
		
		case SHOW_STATS:
		hd44780_gotoxy(0, 0);
        hd44780_puts("                    ");
		hd44780_gotoxy(0, 0);
		hd44780_puts("Stats");		
		break;		
	}
}

static void update_disp_meas(void) {
	switch(meas_ind) {
		case MEAS_RAD:
		{
			char buffer[32];
            uint16_t cpmin;
			cpmin = modbus_get_cpm();
			get_usiv_str(buffer);
			hd44780_gotoxy(1, 0);
			hd44780_puts("                    ");
			hd44780_gotoxy(1, 0);
			hd44780_puts(buffer);
			hd44780_puts(" uS/h");
			utoa(cpmin, buffer, 10);
			hd44780_gotoxy(2, 0);
			hd44780_puts("                    ");
			hd44780_gotoxy(2, 0);
			hd44780_puts(buffer);
			hd44780_puts(" CPM");		
			break;
		}
		case MEAS_TEMP:
		{
			char buffer[32];
            uint16_t* temp = modbus_get_ds18b20_temp();
			hd44780_gotoxy(1, 0);
			hd44780_puts("                    ");
			hd44780_gotoxy(1, 0);
			itoa((int16_t)temp[0], buffer, 10);
			hd44780_puts(buffer);
			hd44780_putc('.');
			utoa((uint16_t)temp[1], buffer, 10);
			hd44780_puts(buffer);
			hd44780_puts(" st. C");
		}
		default:
			break;
	}
}

static void update_disp (void) {
	switch (state) {
		case SHOW_MEAS:
		update_disp_meas();	
		break;
		
		case SHOW_TIME:
		{
			hd44780_gotoxy(1, 0);
			hd44780_puts("                    ");
			hd44780_gotoxy(1, 0);
			if (use_utc) { hd44780_puts(m6242_read_time_str()); }
			else { hd44780_puts(m6242_read_time_str_tz()); }
			hd44780_gotoxy(2, 0);
			hd44780_puts("                    ");
			hd44780_gotoxy(2, 0);
			if (use_utc) { hd44780_puts(m6242_read_date_str()); }
			else { hd44780_puts(m6242_read_date_str_tz()); }	
			break;
		}
		
		case SHOW_STATS:
		{
			char buffer[32];
			hd44780_gotoxy(1, 0);
			hd44780_puts("                    ");
			hd44780_gotoxy(1, 0);
			hd44780_puts("U: ");
			ultoa(uptime(), buffer, 10);
			hd44780_puts(buffer);					
			break;
		}
		
		default:
			break;
	}
}


static void log_data (void) {
    
	static uint32_t timer = 0;
	uint16_t cpmin;
	uint16_t bytes_written;
	char buffer[32];
    
    //Not enpugh samples
    if (uptime() < 60) return;
    
    if ( (uint32_t)(uptime()-timer) >= 1800 ) {		// Once every 30 minutes
        timer = uptime();
        
		res = f_open(&file, "GEIGER.TXT", (FA_OPEN_APPEND | FA_WRITE));
		if (res != FR_OK) {
			modbus_set_cf_result(res);
			return;
		}
		strcpy(buffer, m6242_read_time_str()); 
		f_write(&file, buffer, strlen(buffer), &bytes_written);
		f_write(&file, " ", 1, &bytes_written);
		strcpy(buffer, m6242_read_date_str()); 
		f_write(&file, buffer, strlen(buffer), &bytes_written);			
		f_write(&file, " - ", 3, &bytes_written);
		cpmin = modbus_get_cpm();
		get_usiv_str(buffer);
		f_write(&file, buffer, strlen(buffer), &bytes_written);
		f_write(&file, " uS/h (", 7, &bytes_written);
		utoa(cpmin, buffer, 10);
		f_write(&file, buffer, strlen(buffer), &bytes_written);
		f_write(&file, " CPM)\r\n", 7, &bytes_written);
		f_close(&file);
        modbus_set_cf_time();        
    }   
}


static void key0_func (void) {
	port_clr(BACKLIGHT_PIN);				//Turn the backlight on
	backlight_timer = millis();				//Set timer for backlight utomatic turn off
	if (state == SHOW_MEAS) {
		meas_ind++;
		if (meas_ind >= MEAS_END) { meas_ind = MEAS_RAD; }
	}
	else {
		state = SHOW_MEAS;
		meas_ind = MEAS_RAD;
	}
	prepare_disp();
	update_disp();
}


static void key1_func (void) {
	port_clr(BACKLIGHT_PIN);				//Turn the backlight on
	backlight_timer = millis();				//Set timer for backlight utomatic turn off
	if (state == SHOW_TIME) {
		use_utc ^= 1;
	}
	else {
		state = SHOW_TIME;
		use_utc = 0x00;
	}
	prepare_disp();
	update_disp();
}


static void key2_func (void) {
	port_clr(BACKLIGHT_PIN);				//Turn the backlight on
	backlight_timer = millis();				//Set timer for backlight utomatic turn off
	state = SHOW_STATS;
	prepare_disp();
	update_disp();
}


static void key3_func (void) {
	port_clr(BACKLIGHT_PIN);				//Turn the backlight on
	backlight_timer = millis();				//Set timer for backlight utomatic turn off
}

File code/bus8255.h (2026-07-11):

#ifndef BUS8255_H
#define BUS8255_H

#include <stdint.h>
#include "io.h"

/* Mode 0, Port A = output, Port B = input, Port C = output (unused) */
#define CONF_8255_MODE0_A_OUT_B_IN   0x82

/* ---- Port A bit assignments (open-collector drivers via 7406, inverting) ---- */
#define BIT_PA_1W_OUT   0x08   /* PA3 - 1-Wire bus driver  */
#define BIT_PA_SDA_OUT  0x10   /* PA4 - I2C SDA driver     */
#define BIT_PA_SCL_OUT  0x40   /* PA6 - I2C SCL driver     */

/* ---- Port B bit assignments (bus sense inputs, wired directly to
 * the bus - no buffer, no inversion) ---- */
#define BIT_PB_1W_IN    0x04   /* PB2 - 1-Wire bus sense   */
#define BIT_PB_SDA_IN   0x08   /* PB3 - I2C SDA sense      */

/*
 * Shadow copy of the Port A output latch.
 *
 * PA3/PA4/PA6 drive INVERTING open-collector 7406 buffers, so the
 * *logical* idle state is '0' (driver released, external pull-up
 * holds the bus high) and '1' actively pulls the corresponding bus
 * line low - the opposite of what a non-inverting 7407 would need.
 *
 * We keep a software shadow instead of reading PA_8255 back before
 * every read-modify-write. That avoids ever mixing bits belonging
 * to different buses, and avoids any dependence on whether this
 * particular 8255 part even returns the output latch (rather than
 * the pin state) on a read of an output-configured port.
 */
extern uint8_t porta_shadow;

void bus8255_init(void);

/*
 * Provided elsewhere in your codebase (1MHz 6502, ~16us per call
 * unit). Declared here so onewire.c/i2c_bitbang.c don't need an
 * extra include - delete this line if you'd rather pull the real
 * prototype in from wherever it's already declared.
 */
extern void __fastcall__ delay_16us(uint8_t n);

#endif

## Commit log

2020-08-23 switching state by buttons
2020-08-23 buttons repaired
2020-09-18 PCB added
    [cpu_board.brd, cpu_board.sch, display.brd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]
2020-09-30 Interrupts fixed
2020-10-02 interrupt code optimized
2026-07-01 millis() changed to 16bit
2026-07-01 Millis changed to real 1 ms mode
2026-07-01 io.c/io.h updated to match 16bit/1ms version of millis()
2026-07-01 millis updated to 16 bit
2026-07-05 Onewire and I2C added
2026-07-06 Experiments with ds18b20 temperature sensors
2026-07-06 Temperature readings disabled for now due to freeze issue
    [main.c, read.py]
2026-07-07 Displaying temperature readings
2026-07-07 Reporting temperature reading timestamp
2026-07-07 Way ds18b20 temperature is stored in modbus registers changed
2026-07-11 Code adatped to 7406 inverters on I2C and 1wire lines

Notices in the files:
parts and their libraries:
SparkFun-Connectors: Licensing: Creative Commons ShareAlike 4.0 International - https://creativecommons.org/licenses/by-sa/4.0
